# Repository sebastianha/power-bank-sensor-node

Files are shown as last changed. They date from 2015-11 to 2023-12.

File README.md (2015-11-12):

# power-bank-sensor-node
Tutorial how to build a USB-chargeable temperature / humidity / pressure sensor node in a power bank case which transmits the data via 433MHz to a receiver whose serial protocol is MySensor compatible.

## Example

Here is an image of an earlier version of the sensor node:

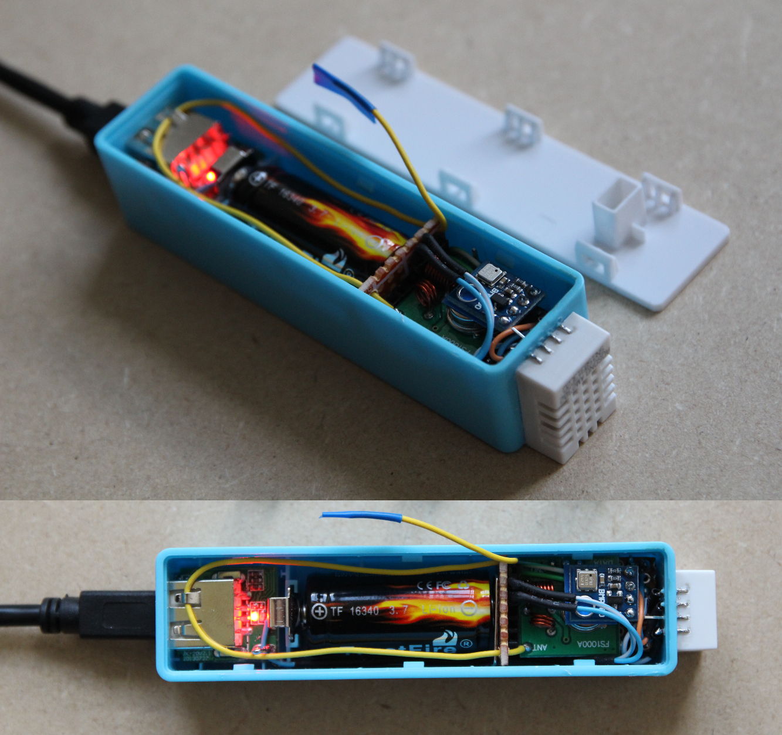
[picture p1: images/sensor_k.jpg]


[Click here for a high-res picture](https://raw.githubusercontent.com/sebastianha/power-bank-sensor-node/master/images/sensor.jpg)

## Prequesites

Here is a list of things to buy:

1. Arduino Pro Mini 8MHz, 3.3V [Ebay](http://www.ebay.de/itm/400985414333)
2. 433 MHz sender module [Ebay](http://www.ebay.de/itm/400985370866)
3. BMP180 pressure sensor [Ebay](http://www.ebay.de/itm/201414876396)
4. DHT22 humidity sensor [Ebay](http://www.ebay.de/itm/400985446261)
5. USB cell phone charger [Ebay](http://www.ebay.de/itm/311142194692)
6. 16340 rechargeable battery [Dealextreme](http://www.dx.com/p/24980)
7. Optional: USB plugs & DS18B20 tempereature sensors [Ebay](http://www.ebay.de/itm/400985334891)

## Schematic

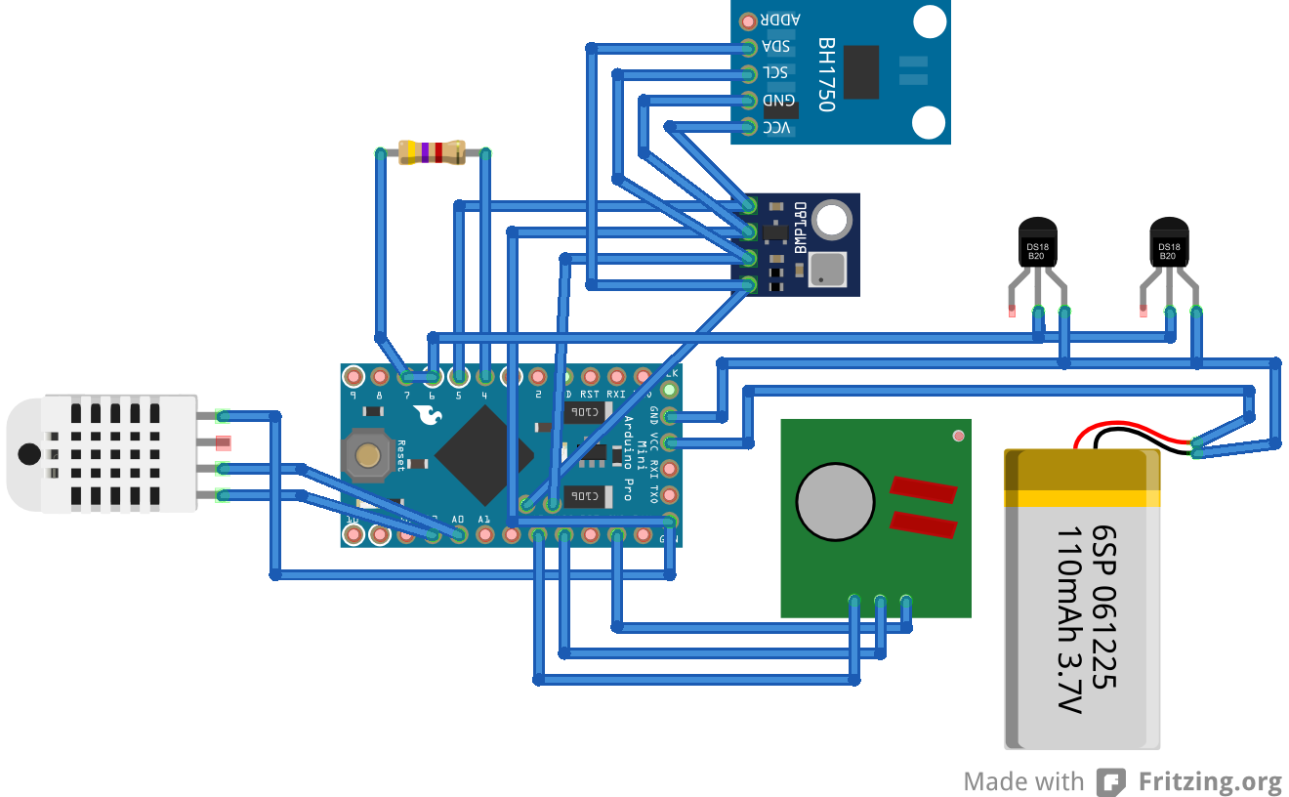
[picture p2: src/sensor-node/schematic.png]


Note: The programming pins of my Arduino seem to have a different order.

## Howto

#### Step 1: Remove unecessary and power hungry parts of the Arduino

Here is the Arduino Pro Mini I used (left picture). First unsolder the reset button (right image, green circle on the left), the power indicator LED (circle in the middle) and the step-down converter on the right.

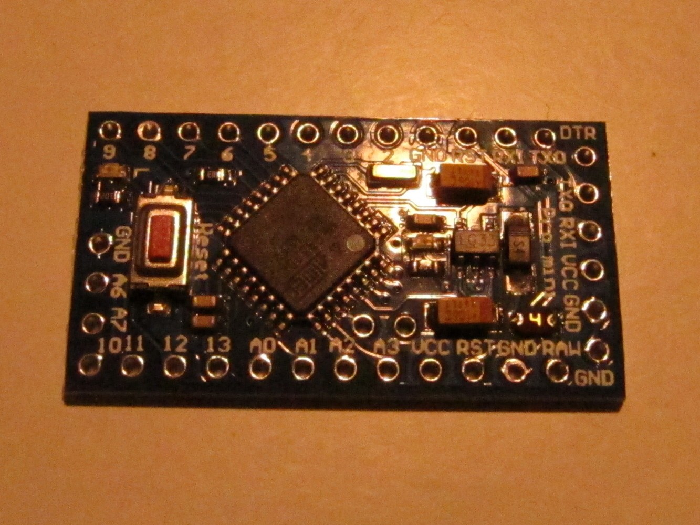
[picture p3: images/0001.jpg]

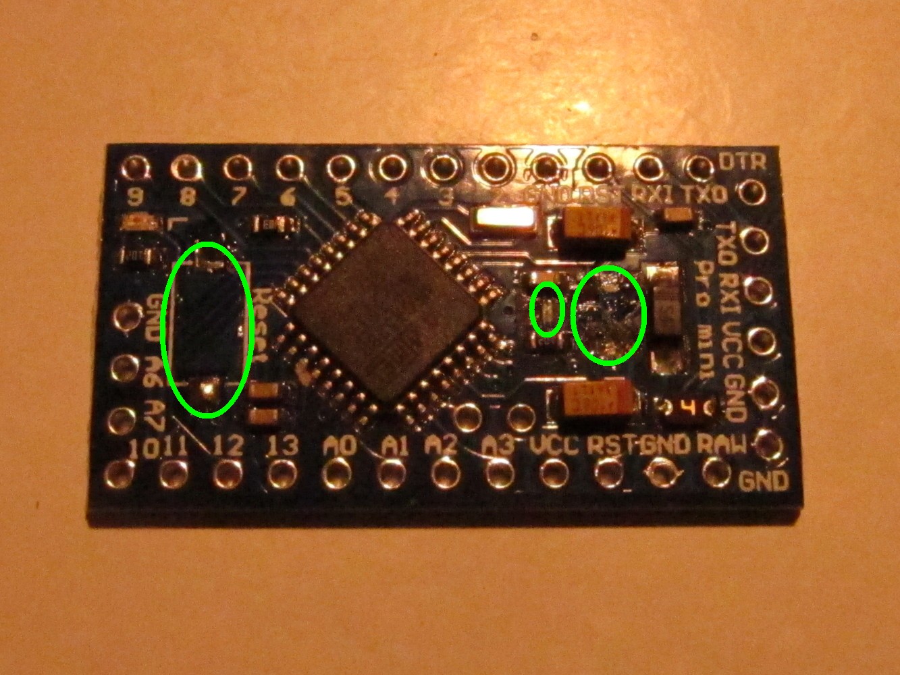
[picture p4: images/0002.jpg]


#### Step 2: Reduce the size of the Arduino

We have to shorten the Arduino so it fits together with the battery into the power bank case. So cut it with a saw between pin 11 and 12 so that pin 12 still remains usable as seen on the left picture. The result can be seen on the right.

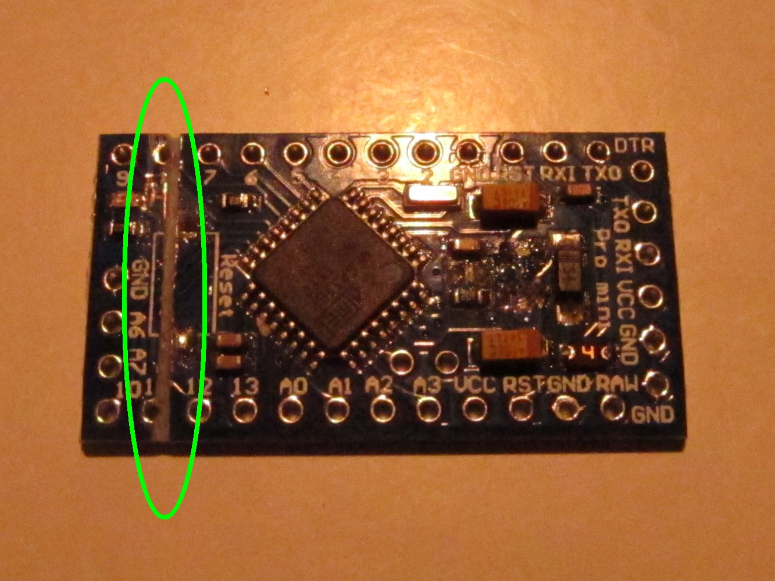
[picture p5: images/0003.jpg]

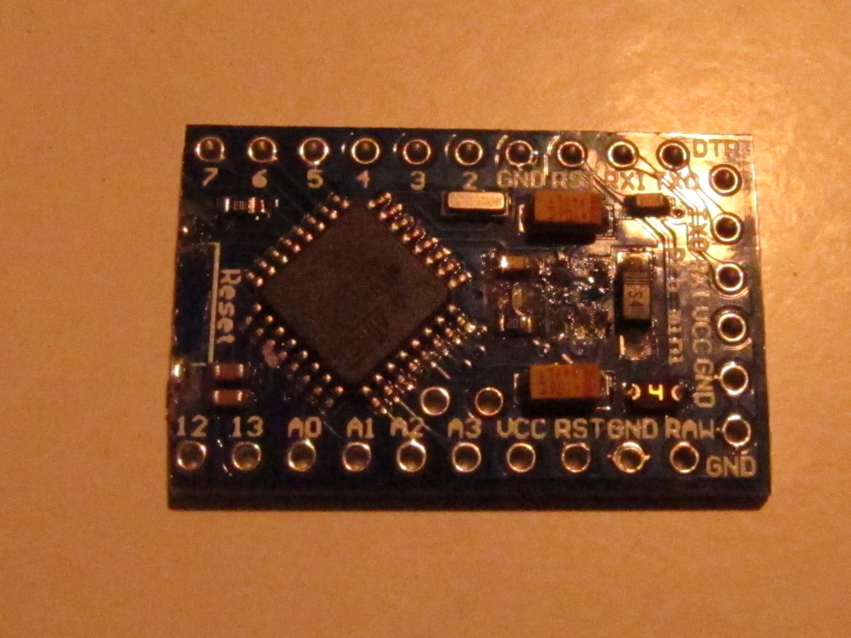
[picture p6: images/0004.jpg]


#### Step 3: Remove the pins of the 433MHz sender

The sender comes with pins that are not needed.

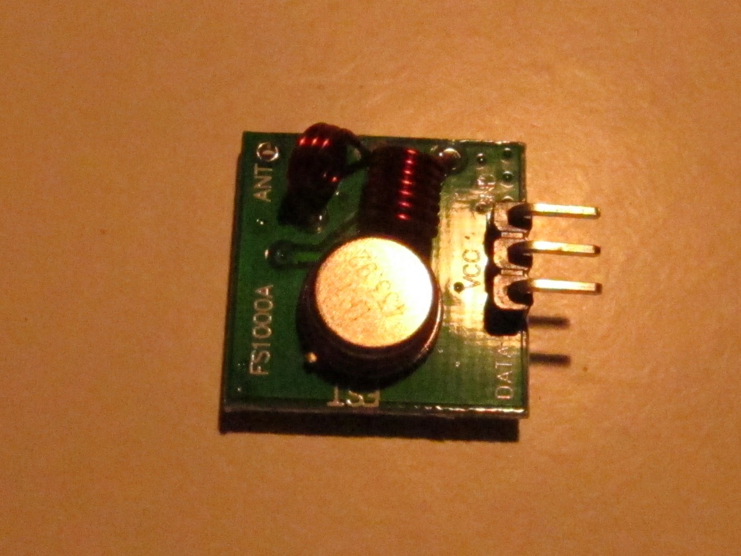
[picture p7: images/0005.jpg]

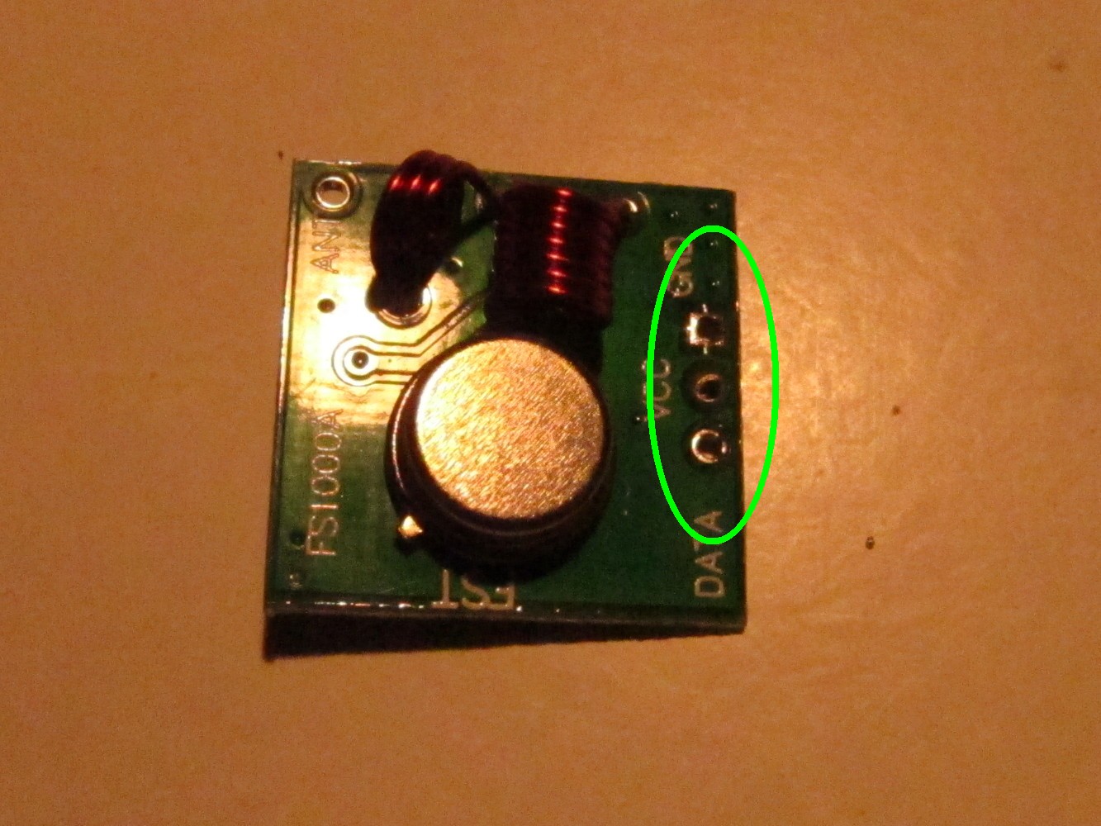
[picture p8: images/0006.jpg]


#### Step 4: Add programming header

Add a female pin header to the Arduino to program it later. The free pin on the right is the second ground pin on the row.

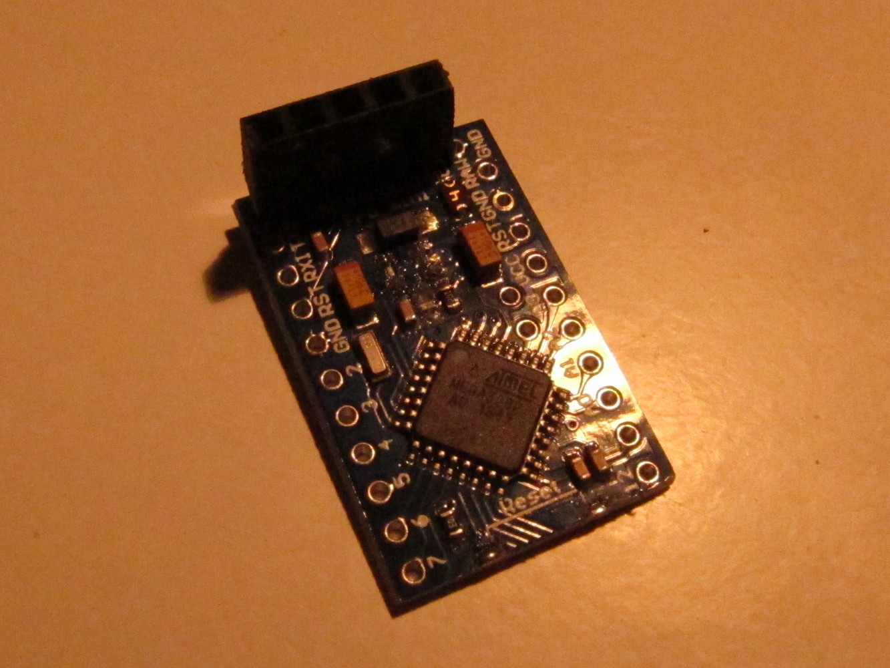
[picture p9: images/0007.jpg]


#### Step 5: Create sender adapter

To connect the sender to the Arduino create an adapter as seen on the left picture. Solder it to GND, VCC and pin A3.

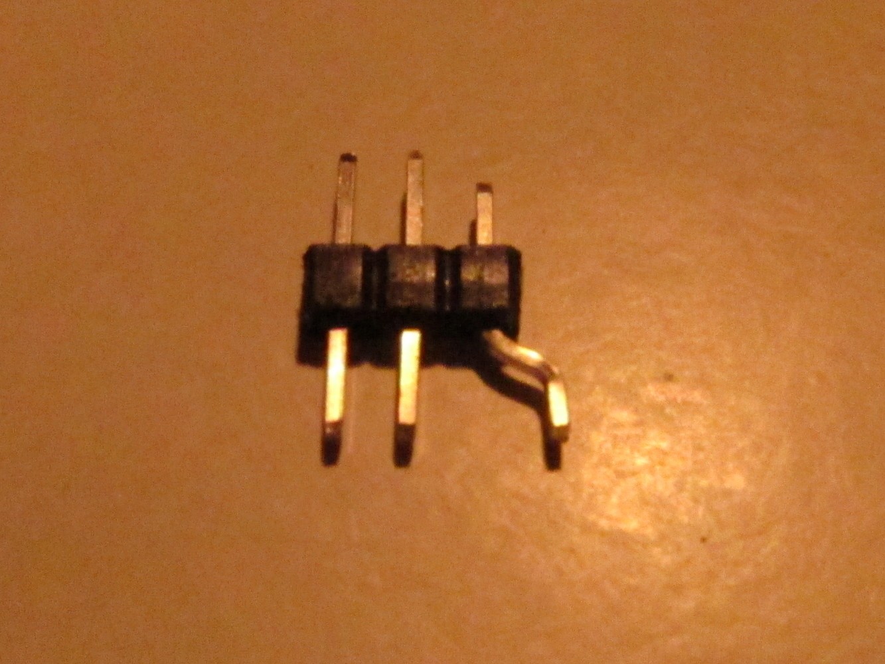
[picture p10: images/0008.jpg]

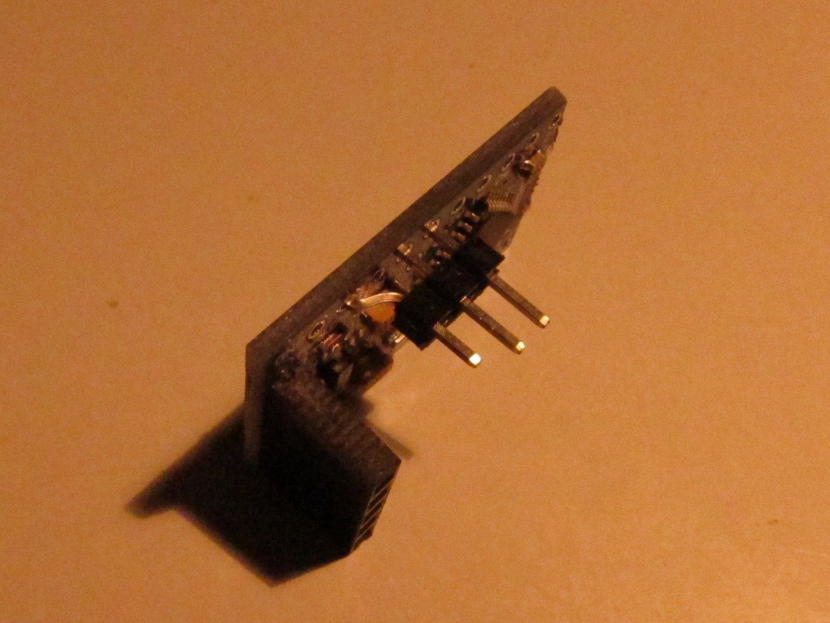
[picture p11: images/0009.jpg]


#### Step 6: Add some cables

Solder two (half blue) cables to the free Arduino GND pin right of the programming headers (green circle at the top). Also add cables to Arduino pin A4 (half green wire) and Arduino A5 (green wire) (green circle in the middle). Remove the plastic connectors of the sender adapter and cut away one section. Then add it on the to straight pins and push it down to the Arduino board as seen on the right picture (green circle)

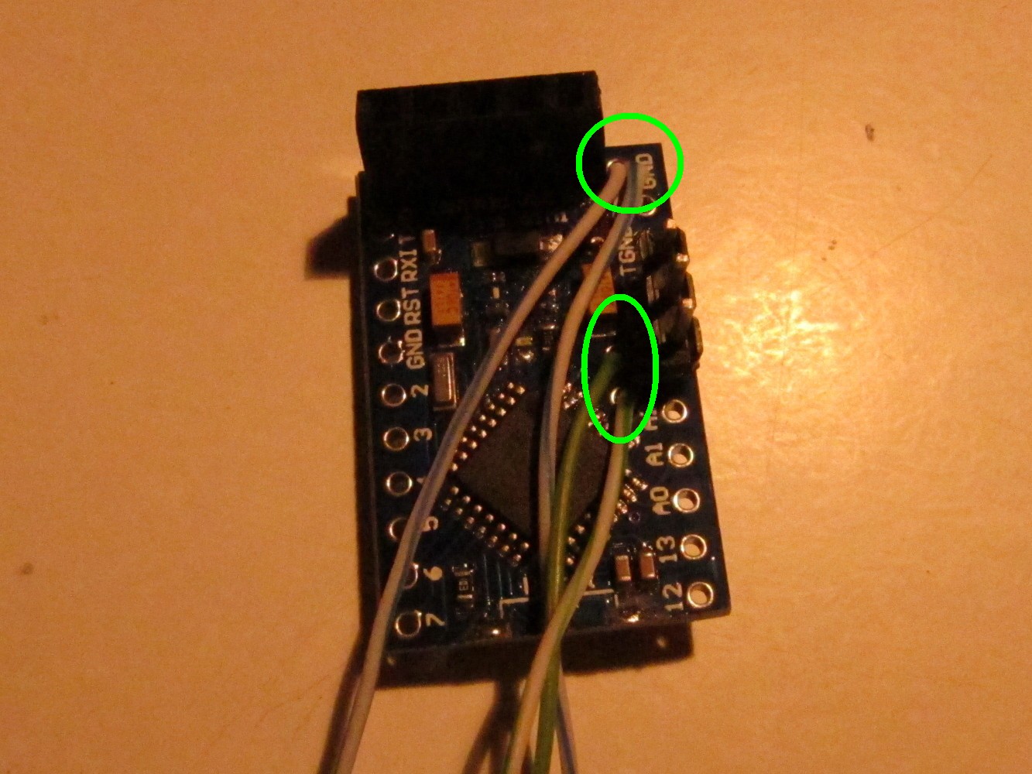
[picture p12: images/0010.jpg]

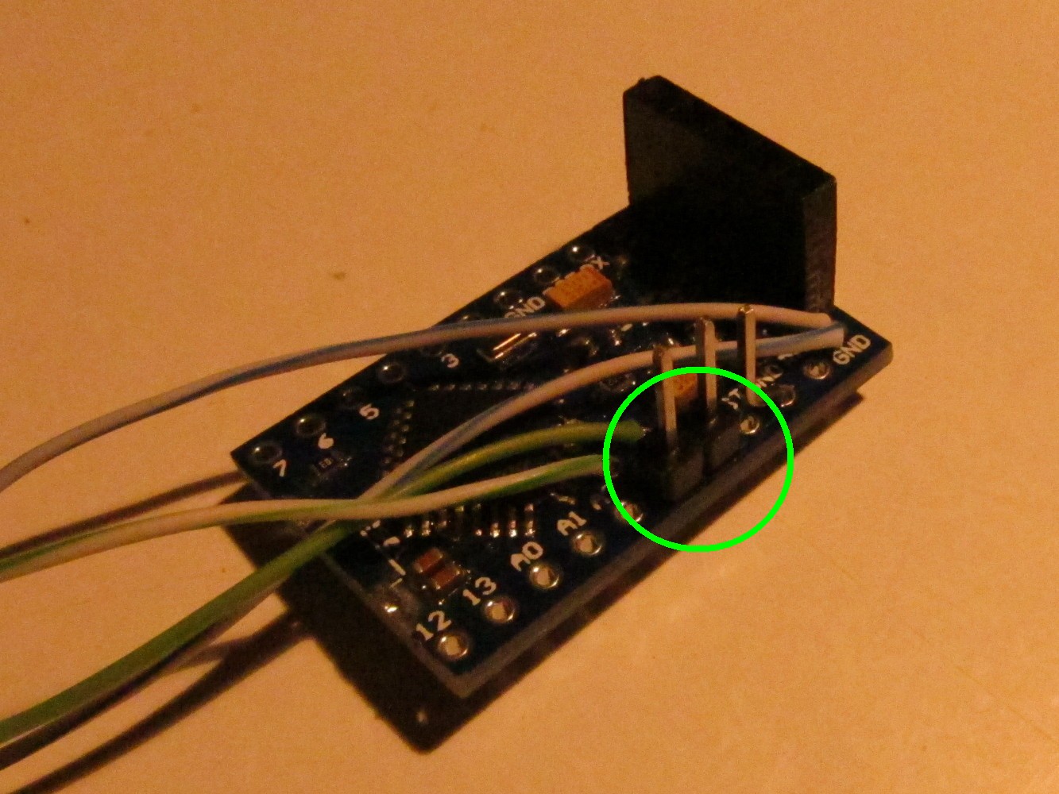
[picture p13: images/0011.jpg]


#### Step 7: Add pull up resistor and connect sender

Solder a 4.7kOhm resistor to Arduino pin 4 and 7 as seen on the left picture (green circle). Then add the sender module on the top connected to the adapter as seen on the picture.

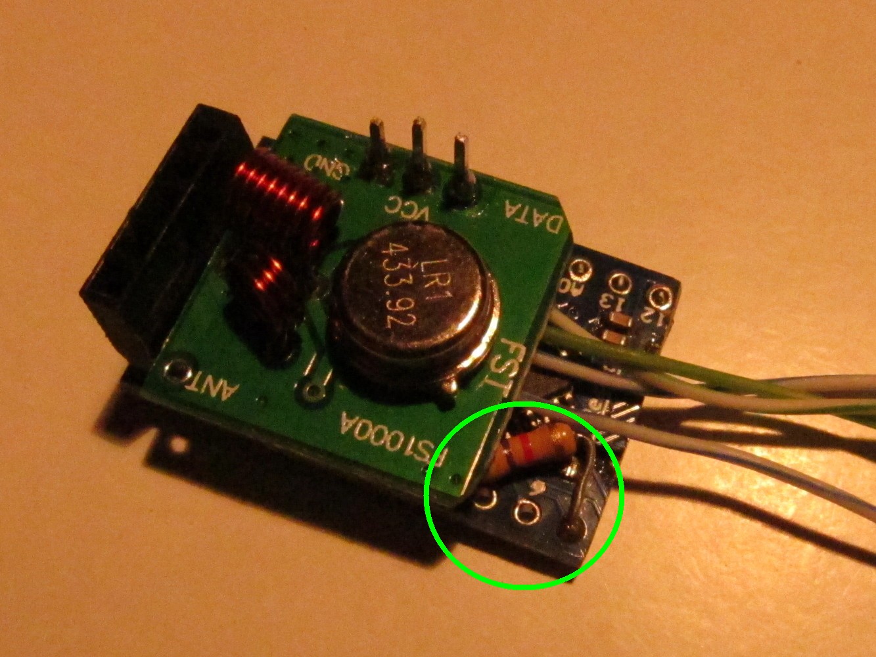
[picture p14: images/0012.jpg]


#### Step 8: Add pin header for the BMP180 sensor

The VCC of the BMP180 sensor will be connected to Arduino pin 5. Therefore a long pin header is soldered to Arduino pin 5 as seen on the picture below (green circle).

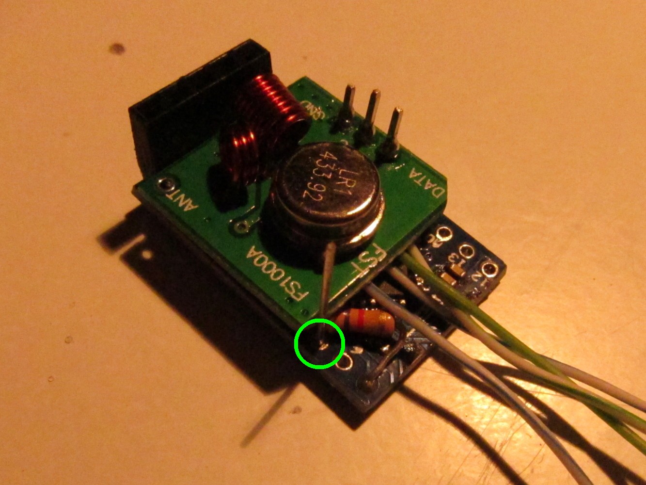
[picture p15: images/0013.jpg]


#### Step 9: Prepare BMP180 sensor

Put a piece of tape on the bottom side of the BMP180 sensor as seen on the right image.

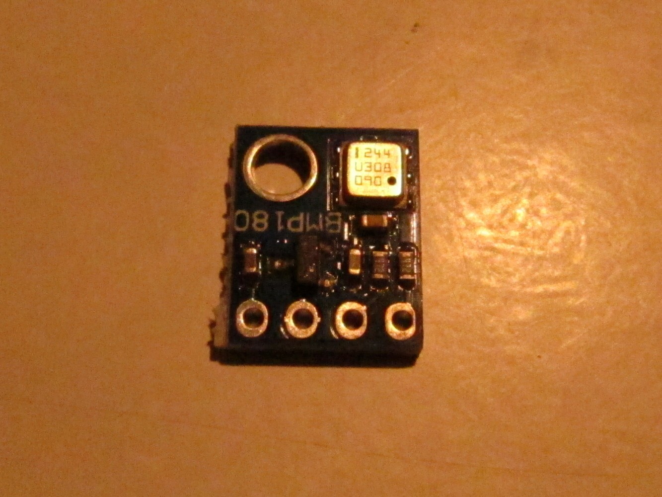
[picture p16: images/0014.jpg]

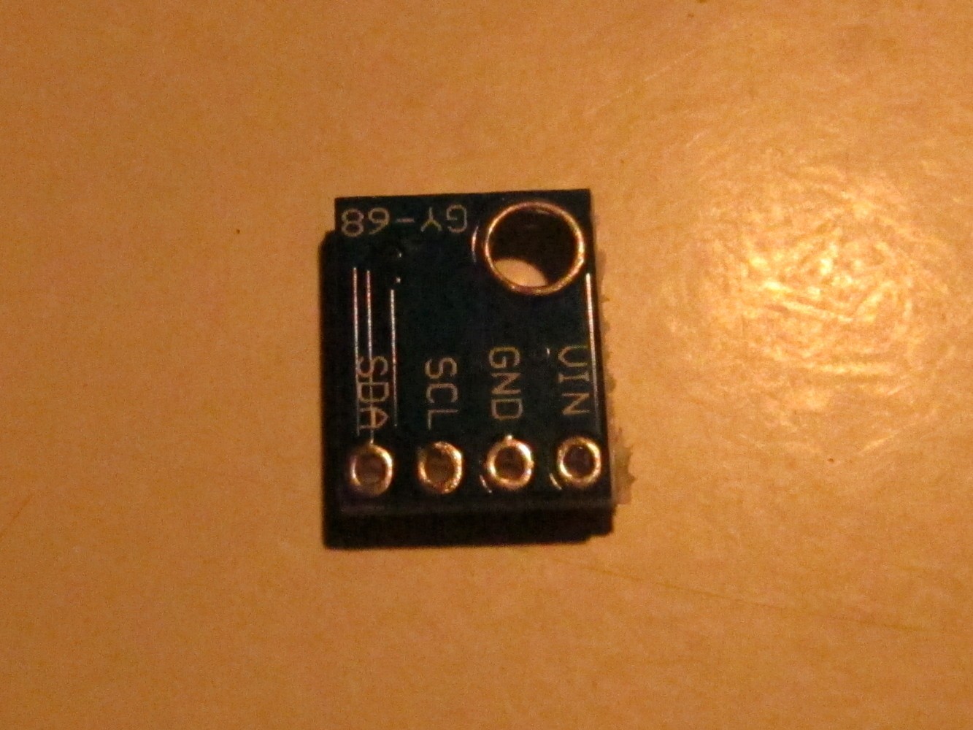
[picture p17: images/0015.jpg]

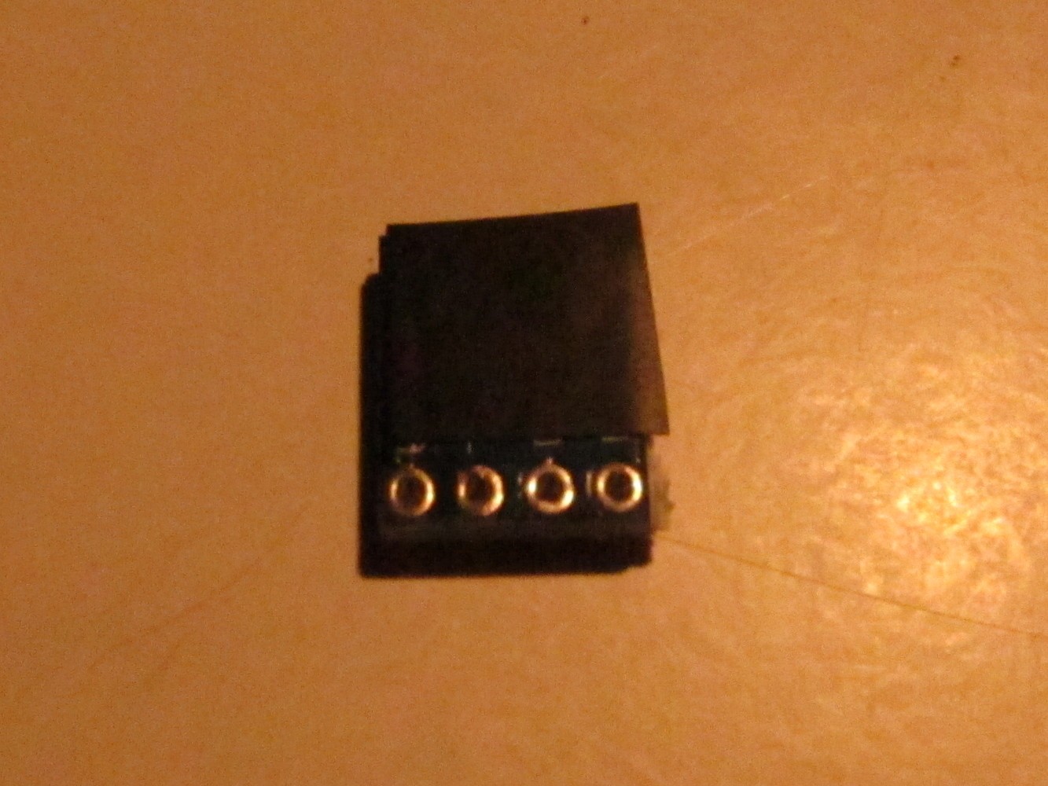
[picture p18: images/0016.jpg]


#### Step 10: Add BMP180 sensor

Cut the green wires and one of the blue ones as seen on the picture. Then solder the BMP180 as seen to the pin header (Arduino pin 5), GND (half blue wire), A5 (green wire) and A4 (half green wire).

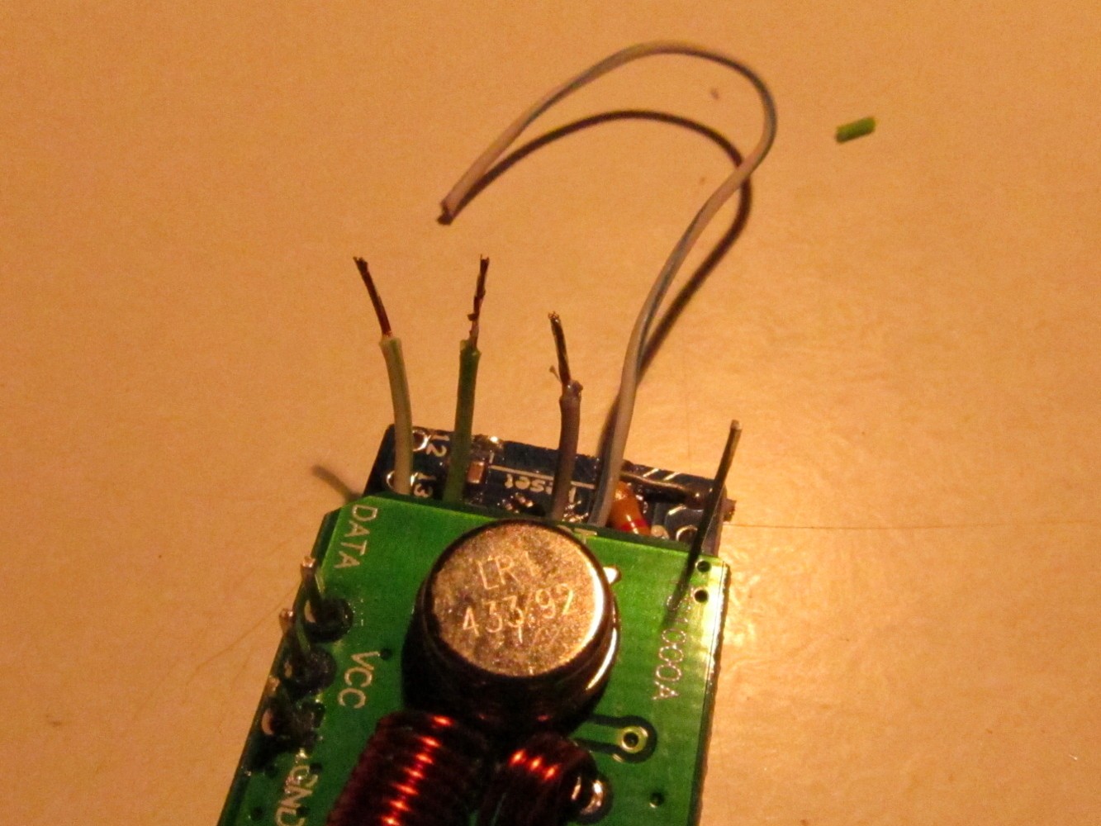
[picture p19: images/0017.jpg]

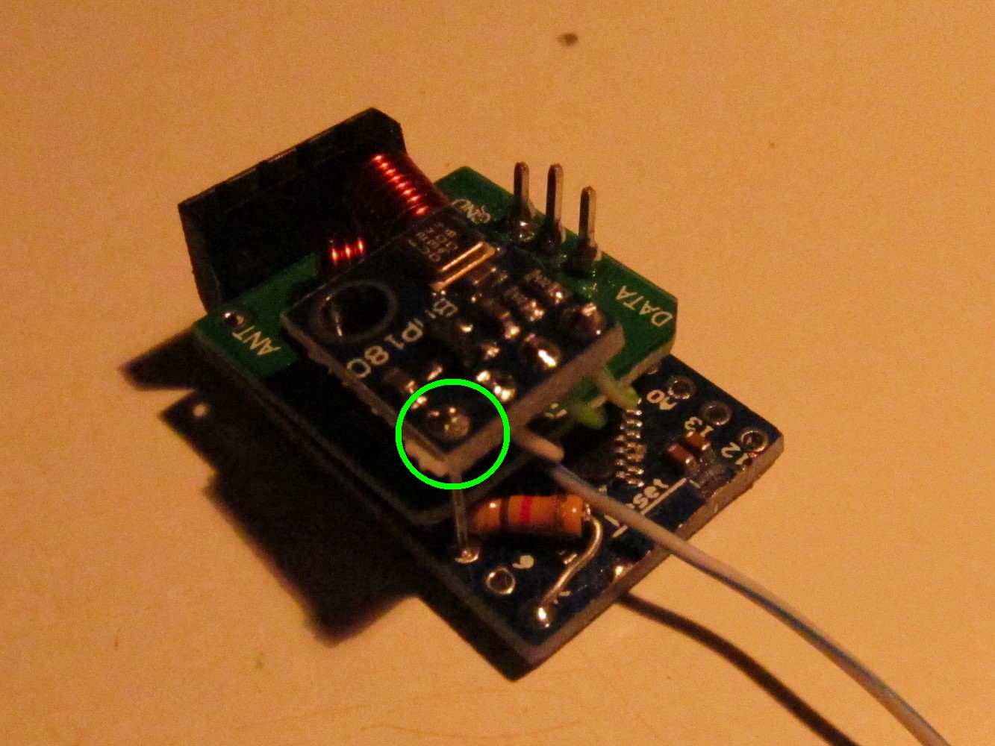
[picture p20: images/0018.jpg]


#### Step 11: Add DS18B20 connector

Solder a long (10cm) wire to Arduino pin 6 as seen on the left picture. On the back side of the Arduino connect pin 6 and pin 7 as seen on the right picture (I forgot it when taking the pictures, that's why it shows a later step).

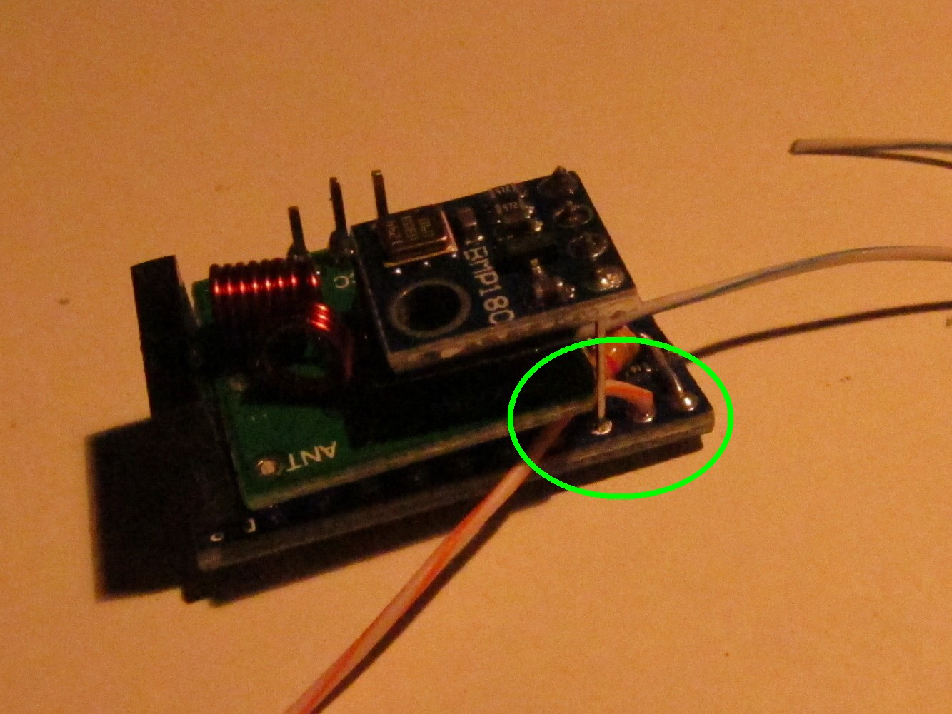
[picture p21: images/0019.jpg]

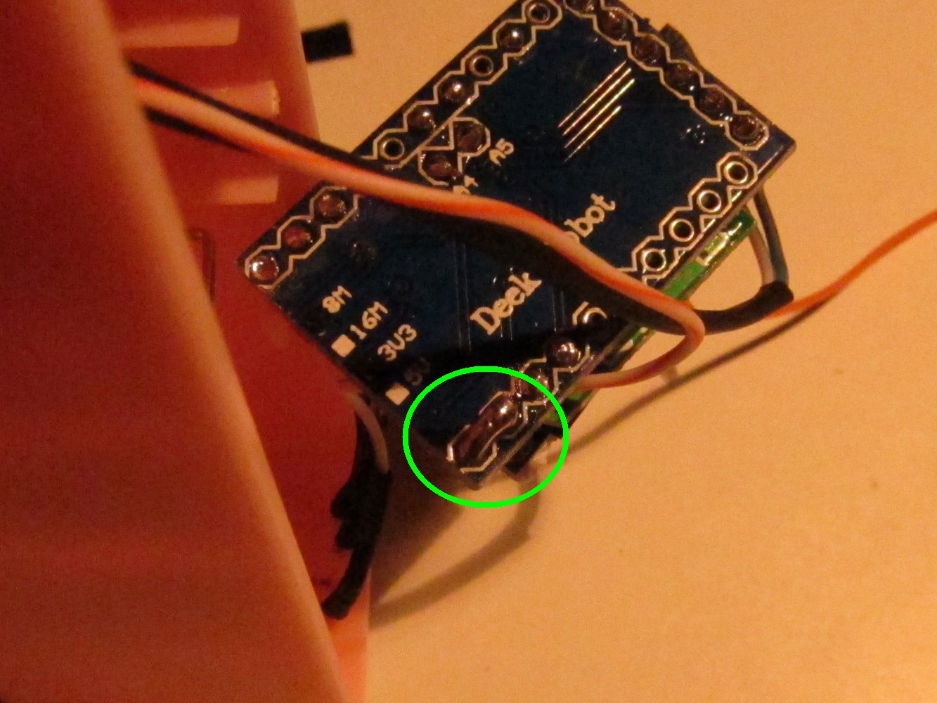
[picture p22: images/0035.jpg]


#### Step 12: The USB power bank cellphone charger case

In general any case like this will work. I found there are small differences between the same looking cases on ebay. Especially when it comes to idle power consumption it might be interesting for this project. As a reference: A "good" case consumes about 0.025-0.050 mAh when idle without anything connected.

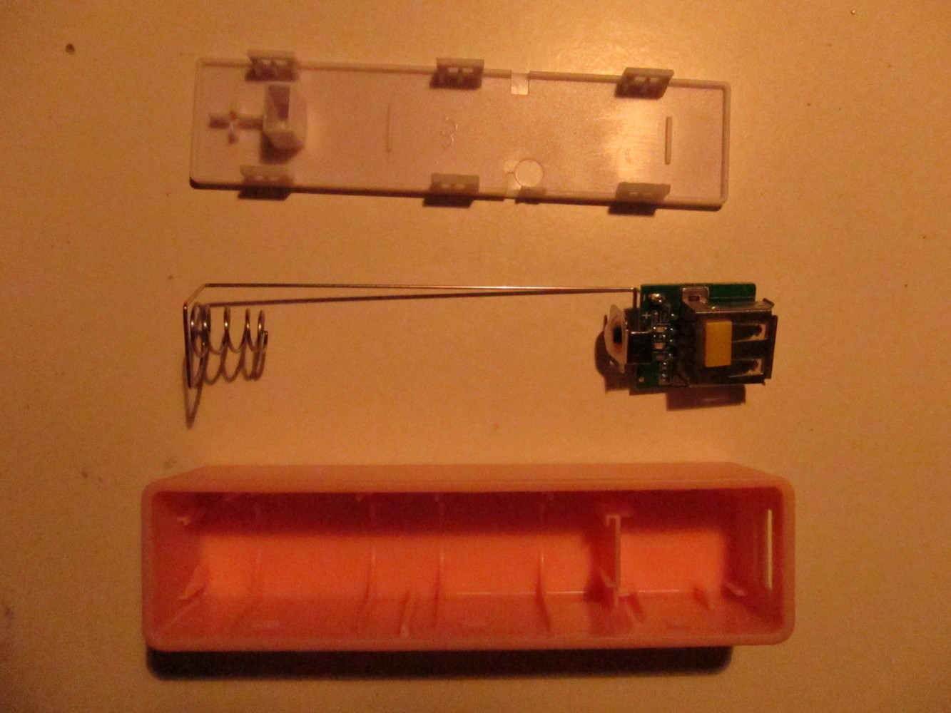
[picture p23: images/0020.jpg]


#### Step 13: Prepare power bank case

The battery holder has to be shortened to fit the 16340 battery. Unsolder it and shorten it as seen on the second picture. Then solder it again to the PCB of the charger (third picture). Check if the battery and the Arduino fits into the case. The result should look like on the most right picture.

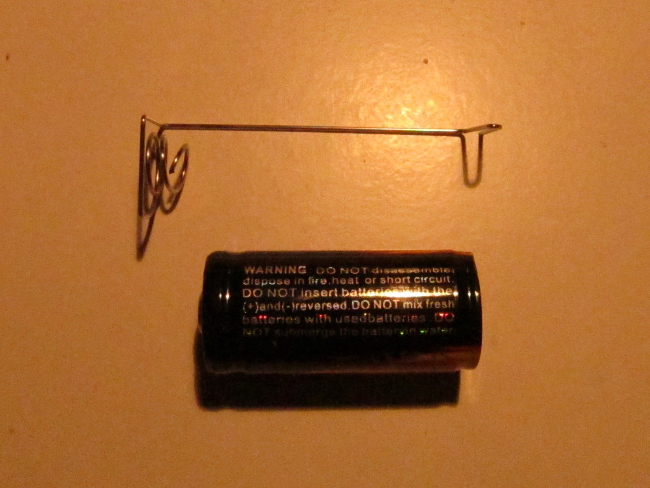
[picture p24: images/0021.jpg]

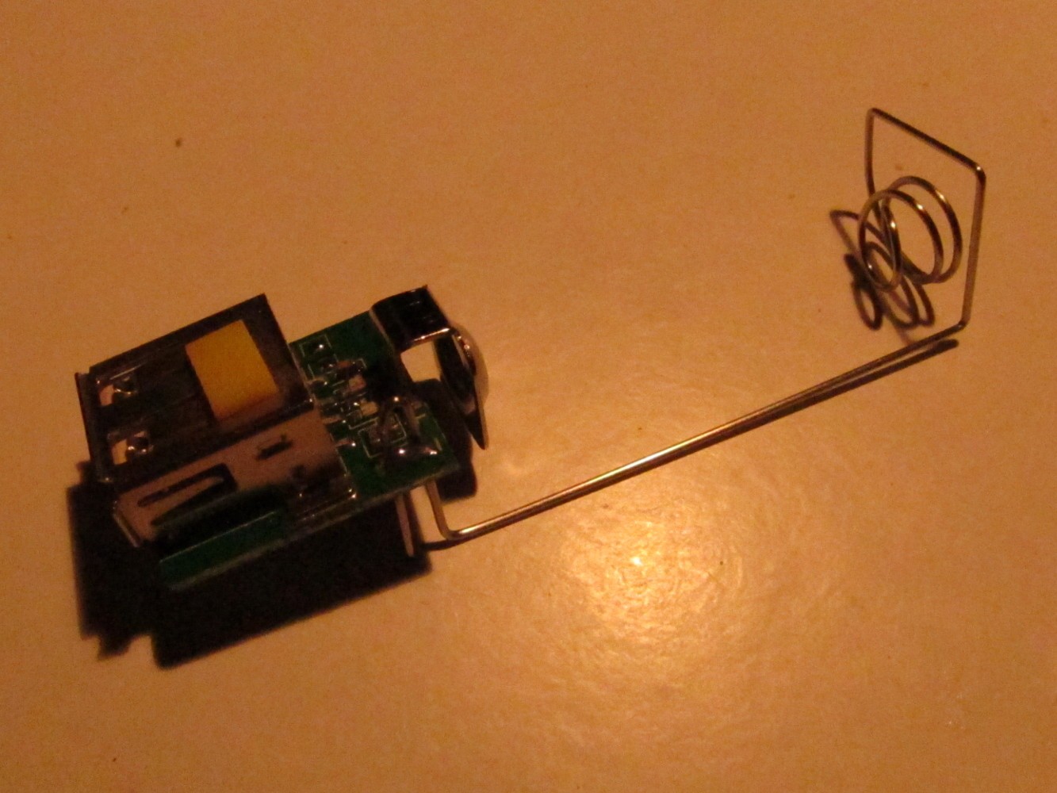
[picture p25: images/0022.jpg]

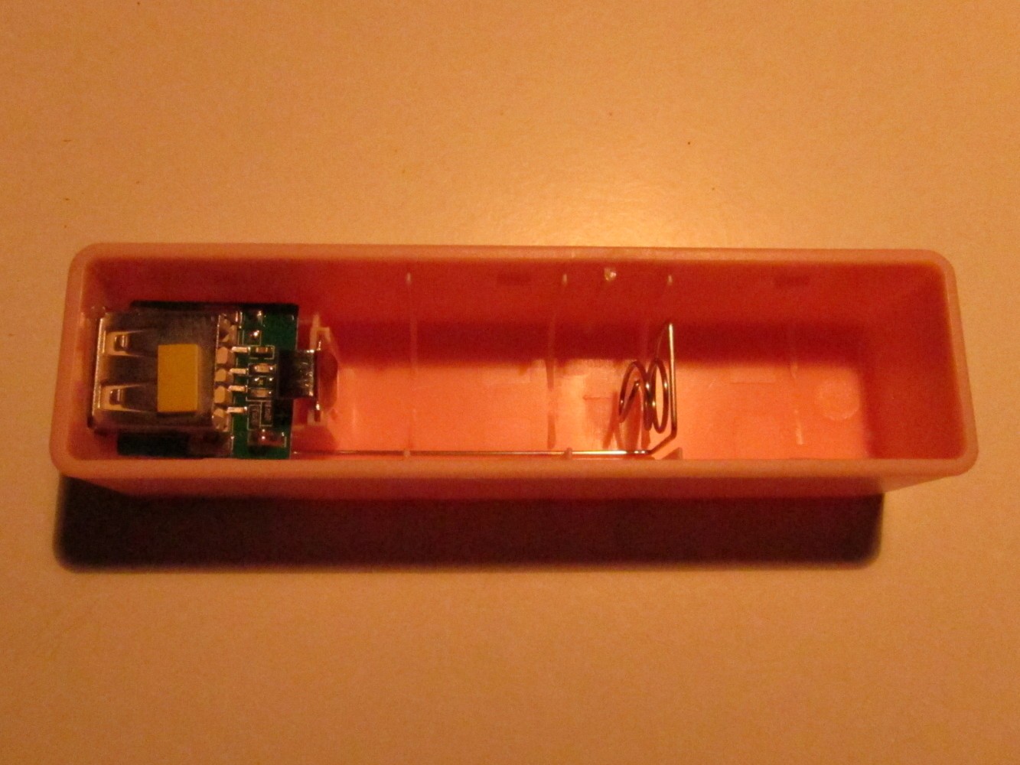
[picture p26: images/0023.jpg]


#### Step 14: Prepare DHT22 sensor

Cut off the upper part of the DTH22 sensor if you like. You could use the loop to fix the case somewhere but the sensor will not fit nicely onto the power bank case. The result is shown on the right picture.

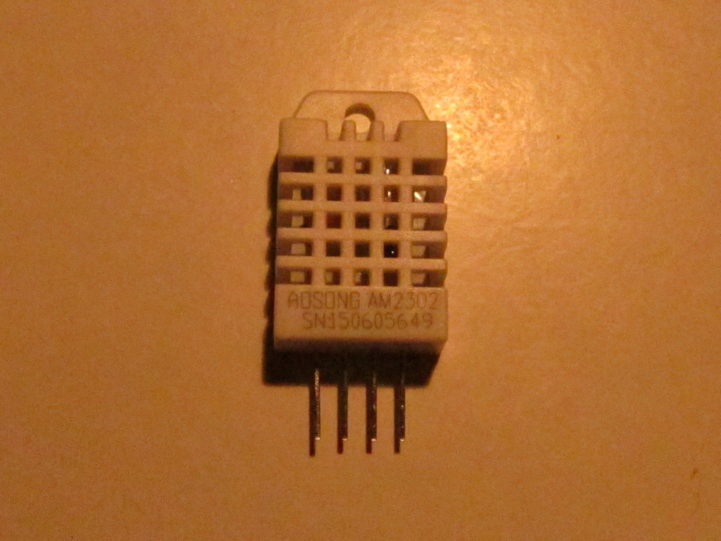
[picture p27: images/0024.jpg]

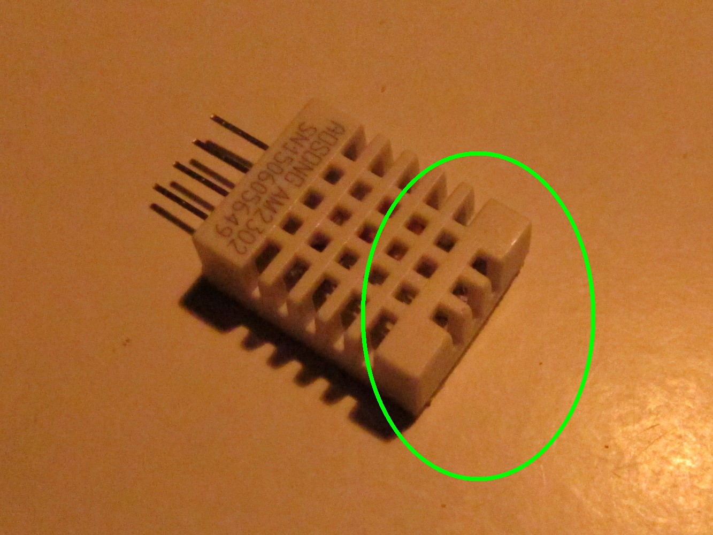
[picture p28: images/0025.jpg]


#### Step 15: Attach DHT22 sensor to power bank case

Pierce the pins of the DHT22 sensor through the case by heating them up with the soldering iron as seen on the left picture. Beware that there has to be enough space for the case cover. Finally, glue it to the case (right picture).

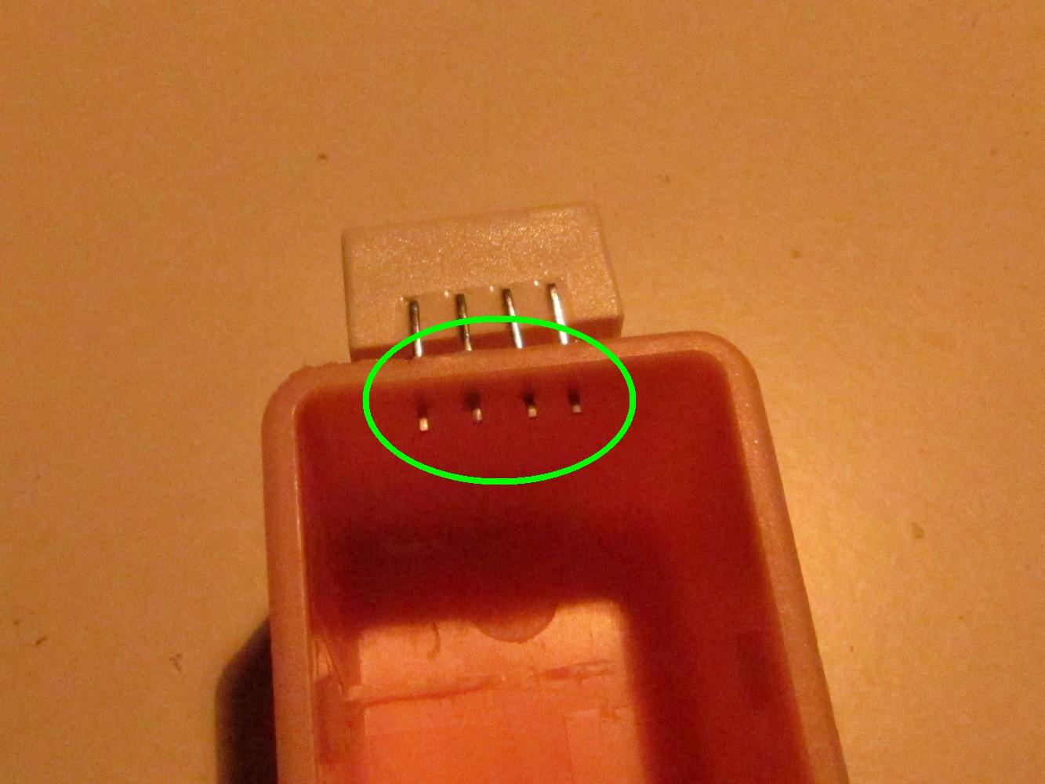
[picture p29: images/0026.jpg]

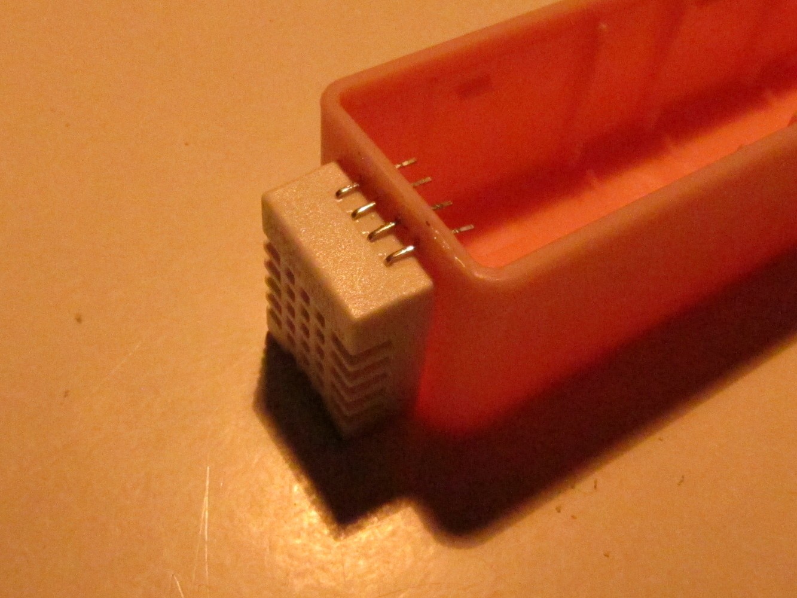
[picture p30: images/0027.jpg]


#### Step 16: Add power cables for the Arduino

Solder a blue cable to the positive pole on the charger PCB and a half blue cable to the negative pole of the charger PCB as seen on the left picture. Cover it with shrinking tube and attach pin headers to it as seen on the right picture.

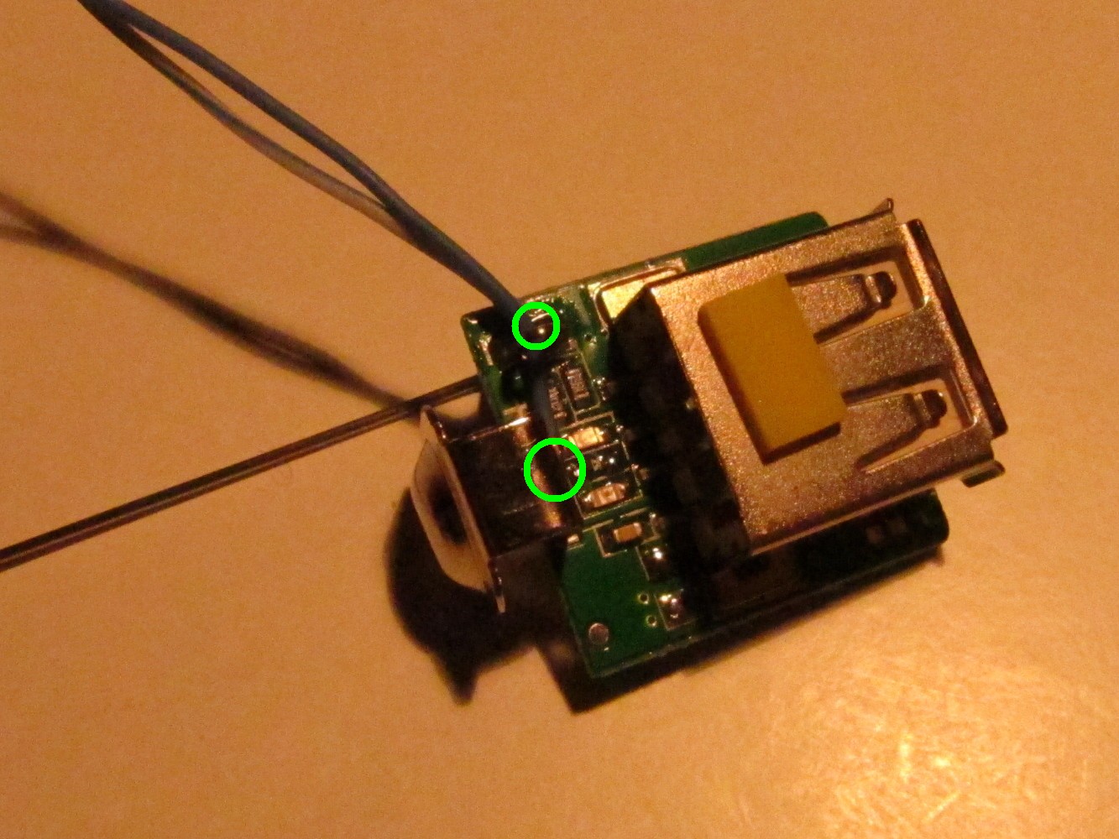
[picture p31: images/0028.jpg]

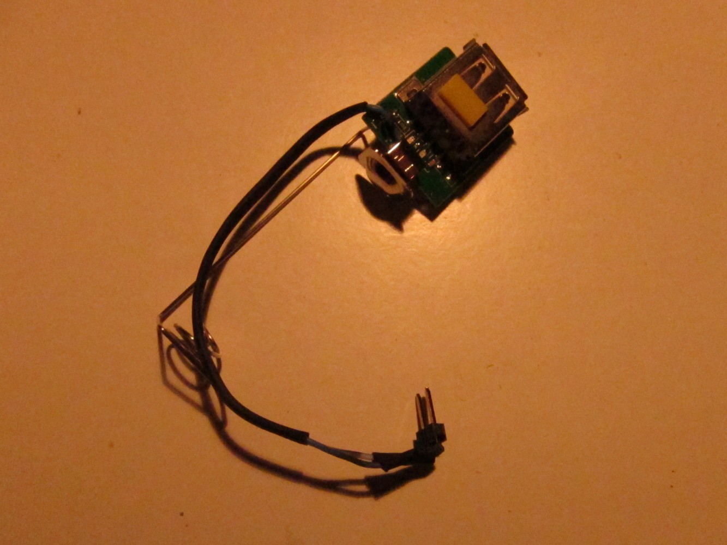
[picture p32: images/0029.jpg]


#### Step 17: Connect DHT22 sensor

Solder a half brown cable to Arduino pin A0 (data) and a brown cable to Arduino pin 13 (VCC) as seen on the left picture. Then connect the DHT22 sensor with these cables and the half blue cable (GND) as seen on the right picture.

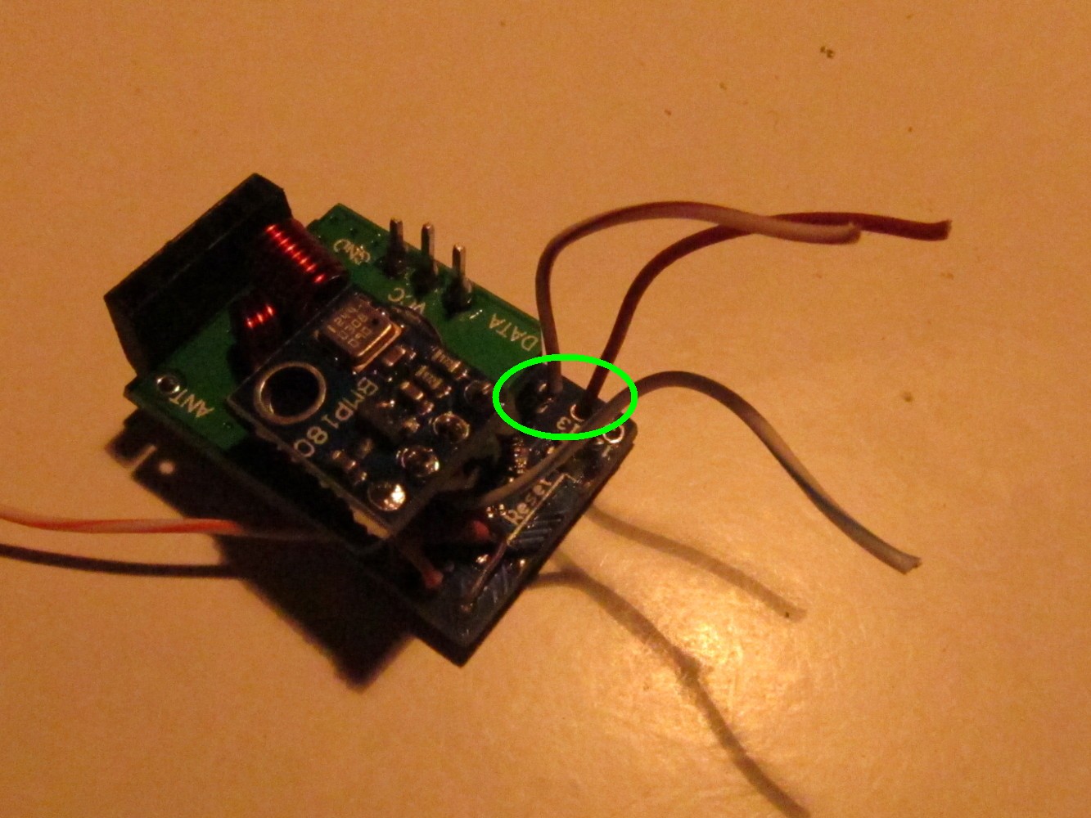
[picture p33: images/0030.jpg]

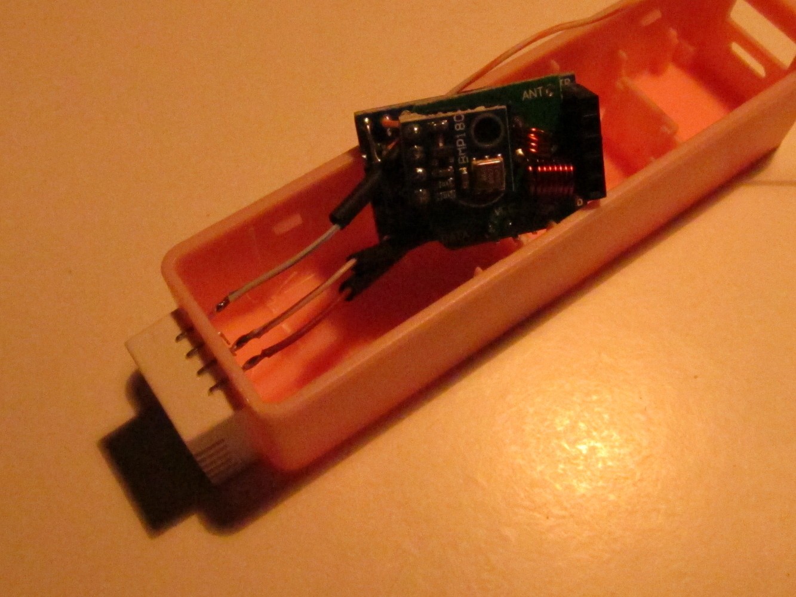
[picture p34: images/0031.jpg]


#### Step 18: Fit everything into the power bank case

Fit everything into the power bank case as seen on the left picture and connect the power connector as seen on the right picture.

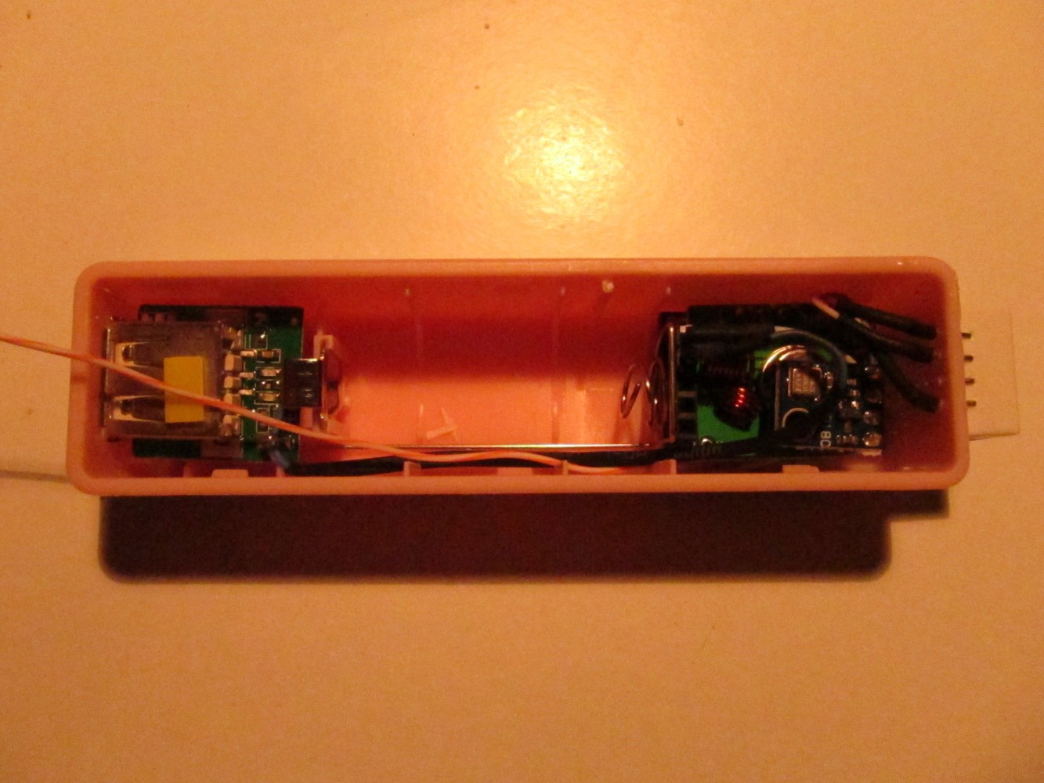
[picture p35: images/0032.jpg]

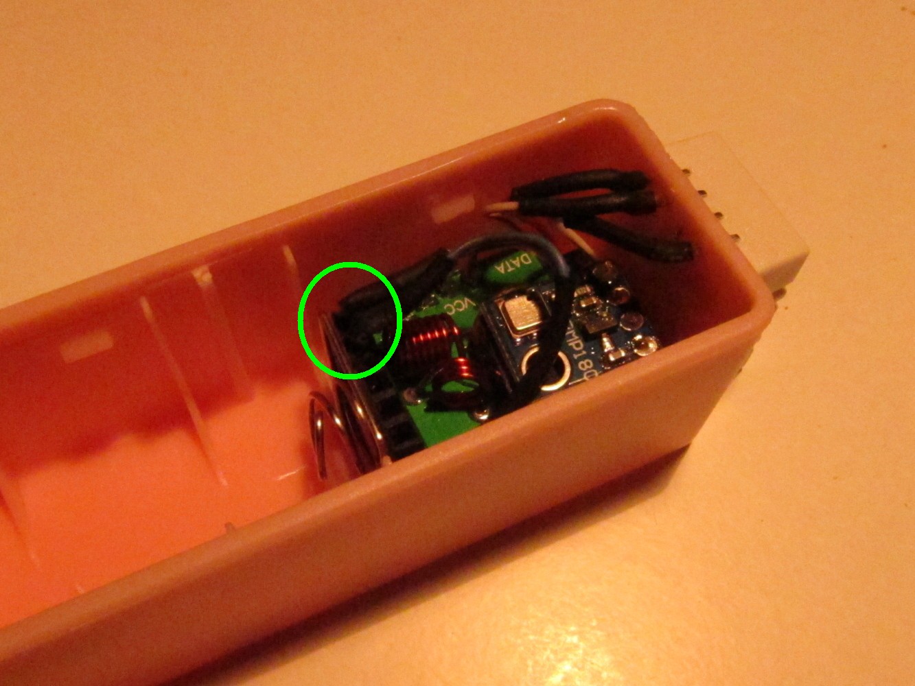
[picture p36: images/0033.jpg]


#### Step 19: Connect DS18B20 data cable

Solder the long, orange cable to the lower USB data connected (the one close to the USB ground).

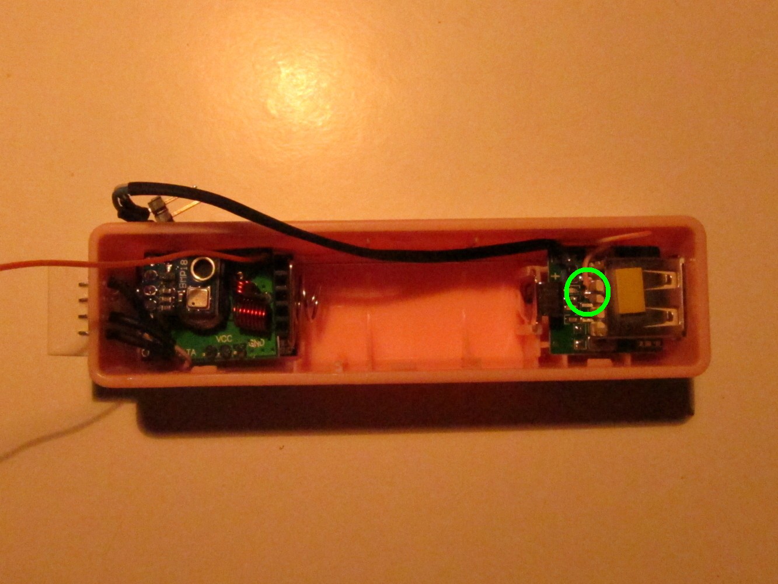
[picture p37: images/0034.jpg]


#### Step 20: Add seperator and attach antenna

Cut a piece of paper as seen on the left picture and place it between the battery holder and the Arduino. Solder a 17.5cm long wire to the antenna pin of the 433MHz sender as seen on the right picture.

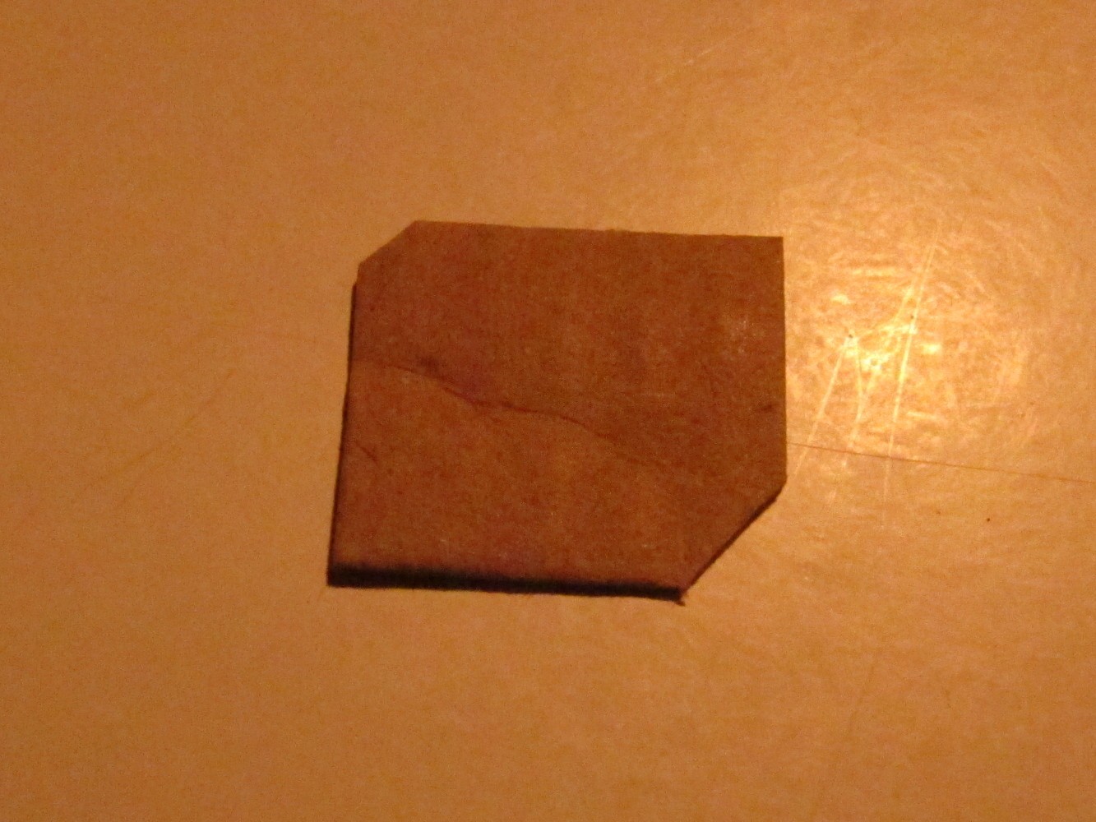
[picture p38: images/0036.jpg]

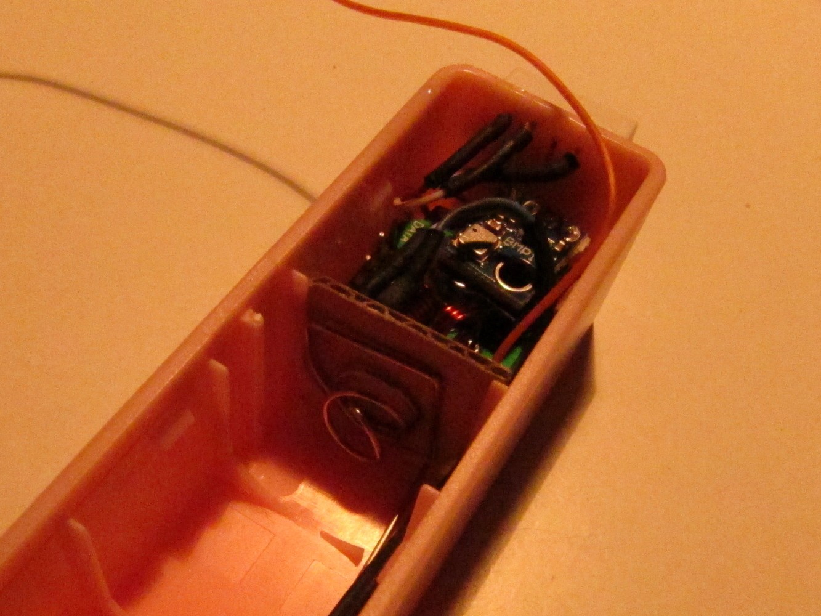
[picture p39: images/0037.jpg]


#### Finish

Assemble everything, it should now look like on the pictures below.

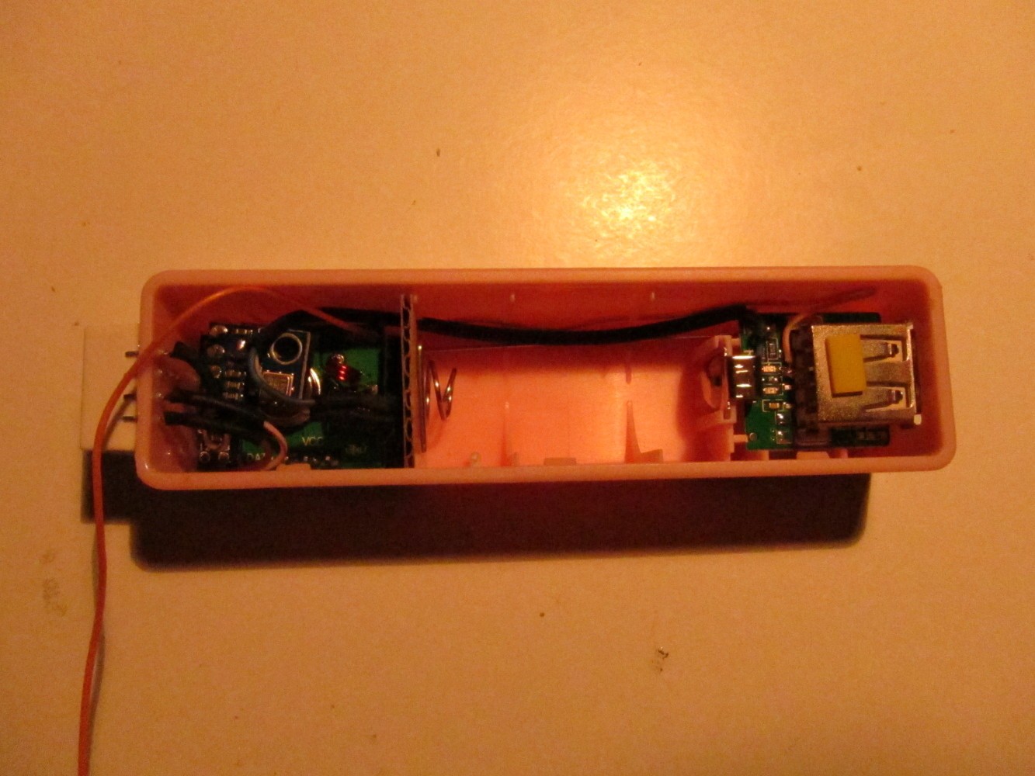
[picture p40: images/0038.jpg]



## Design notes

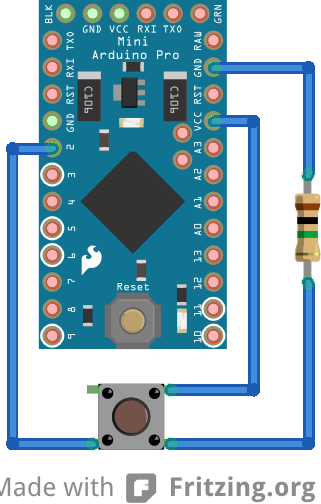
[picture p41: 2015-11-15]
src/window-switch/schematic.png

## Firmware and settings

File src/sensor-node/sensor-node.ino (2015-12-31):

#include <stdint.h>
#include <EEPROM.h>
#include <VirtualWire.h>

/*********************************
***** HARDWARE CONFIGURATION *****
**********************************/

#define RANDOM_PIN              1      // Needs to be an unconnected ANALOG pin to generate UID

#define SLEEP_TIME_8S           7      // Default: 37 for ~5 minutes

#define BATTERY_FULL            4200   // in mV, use max measured voltage
#define BATTERY_EMPTY           2800   // in mV, use cut-off voltage

#define RADIO_RX_PIN            A2     // Not connected
#define RADIO_TX_PIN            A3     // Data pin for sender
#define RADIO_PTT_PIN           2      // Not connected
#define RADIO_REPEAT_MSG        3      // Normally 3 times is enough to ensure data transmission
#define RADIO_BAUD_RATE         2000   // Needs to be adjusted on receiver side, too

#define DHT22_TEMP                     // Enable if DHT22 is connected and temperature should be read
#define DHT22_TEMP_MULTIPLIER   1      // Multiplier
#define DHT22_TEMP_OFFSET       0      // Offset in °C
#define DHT22_HUM                      // Enable if DHT22 is connected and humidity should be read
#define DHT22_HUM_MULTIPLIER    1      // Multiplier
#define DHT22_HUM_OFFSET        0      // Offset in %
#define DHT22_POWER_PIN         13     // Powers the sensor
#define DHT22_PIN               A0     // Data pin for sensor

#define BARO_LIGHT_POWER_PIN    5      // Powers the barometer and or light sensor

#define BARO_TEMP                      // Enable if BMP180 is connected and temperature should be read
#define BARO_TEMP_MULTIPLIER    1      // Multiplier
#define BARO_TEMP_OFFSET        0      // Offset in °C
#define BARO_PRESS                     // Enable if BMP180 is connected and pressure should be read
#define BARO_PRESS_MULTIPLIER   1      // Multiplier
#define BARO_PRESS_OFFSET       0      // Offset in mbar

#define LIGHT                          // Enable if BH1750 is connected and light should be read
#define LIGHT_MULTIPLIER        1      // Multiplier
#define LIGHT_OFFSET            0      // Offset in lux

#define DS18B20                        // Enable if DS18B20 is connected
#define DS18B20_MULTIPLIER      1      // Multiplier
#define DS18B20_OFFSET          0      // Offset in °C
#define DS18B20_POWER_PIN       4      // Powers the sensor
#define DS18B20_PIN             6      // Data pin for sensor

/****************************
***** DO NOT EDIT BELOW *****
*****************************/

// Select sleep method
//#define SLEEP_LOWPOWERLIB // 0.035 mAh
#define SLEEP_NICK // 0.016 mAh

const boolean DEBUG = false;   // Enable debug mode?

#define INT_MIN -32768         // Value for "no sensor value available"
int mp = 0;                    // Message Pointer

const int START_SEQ = 0xFF;    // Start sequence of a message
const uint8_t PROTOCOL_VERSION = 1;

// According to mysensors definition
const int V_TEMP     = 0;
const int V_HUM      = 1;
const int V_PRESSURE = 4;
const int V_LEVEL    = 37;

uint8_t MESSAGE_SEQUENCE_NUMBER = 0;
uint16_t DEVICE_UID = 0;       // is read from EEPROM in setup or generated if not present
                               // Value range is from 10000 to 60000

#ifdef SLEEP_LOWPOWERLIB // https://github.com/rocketscream/Low-Power
  #include <LowPower.h>
#endif

#ifdef SLEEP_NICK // http://www.gammon.com.au/forum/?id=11497
  #include <avr/sleep.h>
  #include <avr/wdt.h>

  ISR (WDT_vect) {
    wdt_disable();
  }

  void sleep1s() {
    // disable ADC
    byte ADCSRA_BACKUP = ADCSRA;
    ADCSRA = 0;

    // clear various "reset" flags
    MCUSR = 0;
    // allow changes, disable reset
    WDTCSR = bit (WDCE) | bit (WDE);
    // set interrupt mode and an interval
    WDTCSR = bit (WDIE) | bit (WDP2) | bit (WDP1);    // set WDIE, and 1 second delay
    wdt_reset();  // pat the dog

    set_sleep_mode (SLEEP_MODE_PWR_DOWN);
    noInterrupts ();           // timed sequence follows
    sleep_enable();

    // turn off brown-out enable in software
    MCUCR = bit (BODS) | bit (BODSE);
    MCUCR = bit (BODS);
    interrupts ();             // guarantees next instruction executed
    sleep_cpu ();

    // cancel sleep as a precaution
    sleep_disable();
    ADCSRA = ADCSRA_BACKUP;
  }
  
  void sleep8s() {
    // disable ADC
    byte ADCSRA_BACKUP = ADCSRA;
    ADCSRA = 0;

    // clear various "reset" flags
    MCUSR = 0;
    // allow changes, disable reset
    WDTCSR = bit (WDCE) | bit (WDE);
    // set interrupt mode and an interval
    WDTCSR = bit (WDIE) | bit (WDP3) | bit (WDP0);    // set WDIE, and 8 seconds delay
    wdt_reset();  // pat the dog

    set_sleep_mode (SLEEP_MODE_PWR_DOWN);
    noInterrupts ();           // timed sequence follows
    sleep_enable();

    // turn off brown-out enable in software
    MCUCR = bit (BODS) | bit (BODSE);
    MCUCR = bit (BODS);
    interrupts ();             // guarantees next instruction executed
    sleep_cpu ();

    // cancel sleep as a precaution
    sleep_disable();
    ADCSRA = ADCSRA_BACKUP;
  }
#endif

#if defined(DHT22_TEMP) || defined(DHT22_HUM)
  #include <dht.h>
  dht DHT;
#endif

#if defined(BARO_TEMP) || defined(BARO_PRESS)
  #include <SFE_BMP180.h>
  SFE_BMP180 pressure;
#endif

#ifdef LIGHT
  #include <Wire.h>
  #include <BH1750.h>
  BH1750 lightMeter;
#endif

#ifdef DS18B20
  #include <OneWire.h>
  OneWire ds(DS18B20_PIN);
#endif

union {
  int i = 0;
  unsigned char b[2];
} uid, bat, temp, hum, baro_t, ds_t1;

union {
  unsigned int u = 0;
  unsigned char b[2];
} light;

union {
  float f = 0;
  unsigned char b[4];
} baro_p;

// from http://provideyourown.com/2012/secret-arduino-voltmeter-measure-battery-voltage/
int readVcc() {
  // Read 1.1V reference against AVcc
  // set the reference to Vcc and the measurement to the internal 1.1V reference
  #if defined(__AVR_ATmega32U4__) || defined(__AVR_ATmega1280__) || defined(__AVR_ATmega2560__)
    ADMUX = _BV(REFS0) | _BV(MUX4) | _BV(MUX3) | _BV(MUX2) | _BV(MUX1);
  #elif defined (__AVR_ATtiny24__) || defined(__AVR_ATtiny44__) || defined(__AVR_ATtiny84__)
    ADMUX = _BV(MUX5) | _BV(MUX0);
  #elif defined (__AVR_ATtiny25__) || defined(__AVR_ATtiny45__) || defined(__AVR_ATtiny85__)
    ADMUX = _BV(MUX3) | _BV(MUX2);
  #else
    ADMUX = _BV(REFS0) | _BV(MUX3) | _BV(MUX2) | _BV(MUX1);
  #endif  
 
  delay(2); // Wait for Vref to settle
  ADCSRA |= _BV(ADSC); // Start conversion
  while (bit_is_set(ADCSRA,ADSC)); // measuring
 
  uint8_t low  = ADCL; // must read ADCL first - it then locks ADCH  
  uint8_t high = ADCH; // unlocks both
 
  long result = (high<<8) | low;
 
  result = 1125300L / result; // Calculate Vcc (in mV); 1125300 = 1.1*1023*1000
  return int(result); // Vcc in millivolts
}

void measure(void) {
  mp = 7; // Set message pointer after battery readings
  // INITIALIZE SENSOR VALUES
  bat.i    = INT_MIN;
  temp.i   = INT_MIN;
  hum.i    = INT_MIN;
  baro_t.i = INT_MIN;
  light.u  = INT_MIN;
  ds_t1.i  = INT_MIN;
  baro_p.f = INT_MIN;


  MESSAGE_SEQUENCE_NUMBER+=1; // increase sequence number to avoid duplicate messages
  if(DEBUG) {
    Serial.print("Message Sequence Number: ");
    Serial.print(MESSAGE_SEQUENCE_NUMBER);
  }

  //               Protocoll
  //               |Message sequence number
  //               ||Device UID
  //               ||| Battery information
  //               ||| | DHT22 Temperature
  //               ||| | |  DHT22 Humidity
  //               ||| | |  |  BMP180 Temperature
  //               ||| | |  |  |  BMP180 Pressure
  //               ||| | |  |  |  |    BH1750 Light
  //               ||| | |  |  |  |    |  DS18B20 Temperatures
  //               ||| | |  |  |  |    |  |
  byte msg[28] = "S    BBTTTHHHTTTPPPPPLLLTTT";
  //              012345678901234567890123456

  // copy static values to message
  memcpy(msg+0,  &START_SEQ, 1);
  memcpy(msg+1,  &PROTOCOL_VERSION, 1);
  memcpy(msg+2,  &MESSAGE_SEQUENCE_NUMBER, 1);
  memcpy(msg+3,  &DEVICE_UID, 2);
  
  /*************************
  *** READ BATTERY START ***
  **************************/
  int batMv = readVcc();
  bat.i = (float(batMv-BATTERY_EMPTY) / float(BATTERY_FULL-BATTERY_EMPTY)) * 10000.0f;
  if(bat.i > 10000)
    bat.i = 10000;
  if(DEBUG) {
    Serial.print("   Battery: ");
    Serial.print(batMv);
    Serial.print(" mV (");
    Serial.print(float(bat.i/100.0f));
    Serial.println(" %)");
  }
  memcpy(msg+5, bat.b, 2);
  /*************************
  ***  READ BATTERY END  ***
  **************************/
  
  // Power up sensors and wait some time to "charge"
  #if defined(DHT22_TEMP) || defined(DHT22_HUM)
    digitalWrite(DHT22_POWER_PIN, HIGH);
    digitalWrite(DHT22_PIN, HIGH);
  #endif
  #ifdef DS18B20
    digitalWrite(DS18B20_POWER_PIN, HIGH);
  #endif
  
  delay(700);
  
  /*************************
  ***  READ DHT22 START  ***
  **************************/
  #if defined(DHT22_TEMP) || defined(DHT22_HUM)
    if(DHT.read22(DHT22_PIN) == DHTLIB_OK) {
      temp.i = int((DHT.temperature * DHT22_TEMP_MULTIPLIER + DHT22_TEMP_OFFSET) * 100);
      hum.i  = int((DHT.humidity    * DHT22_HUM_MULTIPLIER  + DHT22_HUM_OFFSET ) * 100);

      if(DEBUG) {
        Serial.print("Temp1: ");
        Serial.print(float(temp.i/100.0f));
        Serial.print(" C   Humid: ");
        Serial.print(float(hum.i/100.0f));
        Serial.print(" %");
      }
    }

    #ifdef DHT22_TEMP
      memcpy(msg+mp+0, &V_TEMP, 1);
      memcpy(msg+mp+1, temp.b, 2);
      mp += 3;
    #endif
    #ifdef DHT22_HUM
      memcpy(msg+mp+0, &V_HUM, 1);
      memcpy(msg+mp+1, hum.b, 2);
      mp += 3;
    #endif
  #endif
  /*************************
  ***   READ DHT22 END   ***
  **************************/

  /*************************
  ***   READ BMP START   ***
  **************************/
  #if defined(BARO_TEMP) || defined(BARO_PRESS)
    char status;
    double T,P;

    status = pressure.startTemperature();
    if (status != 0) {
      delay(status);
      status = pressure.getTemperature(T);
      if (status != 0) {
        status = pressure.startPressure(3);
        if (status != 0) {
          delay(status);
          status = pressure.getPressure(P,T);
          if (status != 0) {
            baro_t.i = int(( T * BARO_TEMP_MULTIPLIER  + BARO_TEMP_OFFSET ) * 100);
            baro_p.f = float(P * BARO_PRESS_MULTIPLIER + BARO_PRESS_OFFSET);
            if(DEBUG) {
              Serial.print("   Temp2: ");
              Serial.print(float(baro_t.i/100.0f));
              Serial.print(" C   Press: ");
              Serial.print(float(baro_p.f));
              Serial.print(" mbar");
            }
          }
        }
      }
    }

    #ifdef BARO_TEMP
      memcpy(msg+mp+0, &V_TEMP, 1);
      memcpy(msg+mp+1, baro_t.b, 2);
      mp += 3;
    #endif
    #ifdef BARO_PRESS
      memcpy(msg+mp+0, &V_PRESSURE, 1);
      memcpy(msg+mp+1, baro_p.b, 4);
      mp += 5;
    #endif
  #endif
  /*************************
  ***    READ BMP END    ***
  **************************/

  /*************************
  ***  READ LIGHT START  ***
  **************************/
  #ifdef LIGHT
    lightMeter.begin(BH1750_ONE_TIME_HIGH_RES_MODE);
    unsigned int lux = lightMeter.readLightLevel();
	light.u = lux * LIGHT_MULTIPLIER + LIGHT_OFFSET;
    if(DEBUG) {
      Serial.print("   Light: ");
      Serial.print(light.u);
      Serial.print(" lx");
    }

    memcpy(msg+mp+0, &V_LEVEL, 1);
    memcpy(msg+mp+1, light.b, 2);
    mp += 3;
  #endif
  /*************************
  ***   READ LIGHT END   ***
  **************************/
  
  /*************************
  *** READ DS18B20 START ***
  **************************/
  #ifdef DS18B20
    byte addr[8];
    byte data[12];
    while(ds.search(addr)) {
      if(!OneWire::crc8(addr, 7) != addr[7]) {
        ds_t1.i  = INT_MIN;
        ds.reset();
        ds.select(addr);
        ds.write(0x44, 1);
        #ifdef SLEEP_LOWPOWERLIB
          LowPower.powerDown(SLEEP_1S, ADC_OFF, BOD_OFF);
        #endif
        #ifdef SLEEP_NICK
          sleep1s();
        #endif
        #if !defined(SLEEP_LOWPOWERLIB) && !defined(SLEEP_NICK)
          delay(1000);
        #endif
        ds.reset();
        ds.select(addr);
        ds.write(0xBE);
        for (int i = 0; i < 9; i++) {
          data[i] = ds.read();
        }
        int16_t raw = (data[1] << 8) | data[0];
        byte cfg = (data[4] & 0x60);
        if (cfg == 0x00) raw = raw & ~7;  // 9 bit resolution, 93.75 ms
        else if (cfg == 0x20) raw = raw & ~3; // 10 bit res, 187.5 ms
        else if (cfg == 0x40) raw = raw & ~1; // 11 bit res, 375 ms
        ds_t1.i = int(((raw / 16.0) * DS18B20_MULTIPLIER + DS18B20_OFFSET) * 100);
        if(DEBUG) {
          Serial.print("   Temp3: ");
          Serial.print(float(ds_t1.i/100.0f));
          Serial.print(" C");
        }

        memcpy(msg+mp+0, &V_TEMP, 1);
        memcpy(msg+mp+1, ds_t1.b, 2);
        mp += 3;
      }
    }
    ds.reset_search();
  #endif
  /*************************
  ***  READ DS18B20 END  ***
  **************************/

  if(DEBUG) Serial.println();

  // Power down sensors
  #if defined(DHT22_TEMP) || defined(DHT22_HUM)
    digitalWrite(DHT22_POWER_PIN, LOW);
    digitalWrite(DHT22_PIN, LOW);
  #endif
  #ifdef DS18B20
    digitalWrite(DS18B20_POWER_PIN, LOW);
  #endif

  // Send data
  for(int i=0; i<RADIO_REPEAT_MSG; i++) {
    vw_send((uint8_t *)msg, mp);
    vw_wait_tx();
    delay(100);
  }
}

void setup(void) {
  if(DEBUG) Serial.begin(57600);
  
  if(DEBUG) {
    Serial.print("PROTOCOL_VERSION: ");
    Serial.println(PROTOCOL_VERSION);
  }
  
  randomSeed(analogRead(RANDOM_PIN));

  // Clear EEPROM DEVICE_UID
  //EEPROM.write(0, 0);
  //EEPROM.write(1, 0);

  uid.b[0] = EEPROM.read(0);
  uid.b[1] = EEPROM.read(1);
  DEVICE_UID = uint16_t(uid.i);
  if(DEVICE_UID == 0) {
    if(DEBUG) Serial.println("Generating new DEVICE_UID because nothing found in EEPROM");
    DEVICE_UID = random(10000, 60000); 
    uid.i = DEVICE_UID;
    EEPROM.write(0, uid.b[0]);
    EEPROM.write(1, uid.b[1]);
  }
  if(DEBUG) {
    Serial.print("DEVICE_UID:       ");
    Serial.println(DEVICE_UID);
  }

  vw_set_tx_pin(RADIO_TX_PIN);
  vw_set_rx_pin(RADIO_RX_PIN);   // Not connected
  vw_set_ptt_pin(RADIO_PTT_PIN); // Not connected
  vw_setup(RADIO_BAUD_RATE);

  #if defined(DHT22_TEMP) || defined(DHT22_HUM)
    pinMode(DHT22_POWER_PIN, OUTPUT);
    pinMode(DHT22_PIN, OUTPUT);
  #endif

  #if defined(BARO_TEMP) || defined(BARO_PRESS) || defined(LIGHT)
    pinMode(BARO_LIGHT_POWER_PIN, OUTPUT);
    digitalWrite(BARO_LIGHT_POWER_PIN, HIGH);
  #endif

  #if defined(BARO_TEMP) || defined(BARO_PRESS)
    delay(500);
    if (pressure.begin()) {
      if(DEBUG) Serial.println("BMP180 init success");
	} else {
      if(DEBUG) Serial.println("BMP180 init fail");
    }
  #endif

  #ifdef DS18B20
    pinMode(DS18B20_POWER_PIN, OUTPUT);
  #endif

  if(DEBUG) Serial.println("\n");
}

unsigned long t;
void loop(void) {
  if(DEBUG) t = millis();
  measure();
  if(DEBUG) {
    Serial.print("Measuring data took ");
    Serial.print(((millis()-t)));
    Serial.println(" ms");
    Serial.println();
  }
  
  // Every ~5 minutes (37*8s)
  if(DEBUG) {
    delay(3000);
  } else {
    for(int i=0; i<SLEEP_TIME_8S; i++) {
      #ifdef SLEEP_LOWPOWERLIB
        LowPower.powerDown(SLEEP_8S, ADC_OFF, BOD_OFF);
      #endif
      #ifdef SLEEP_NICK
        sleep8s();
      #endif
      #if !defined(SLEEP_LOWPOWERLIB) && !defined(SLEEP_NICK)
        delay(8000);
      #endif
    }
  }
}

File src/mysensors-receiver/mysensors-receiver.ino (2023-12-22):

#include <stdint.h>
#include <VirtualWire.h>

const int rx_pin   = 11;
const int tx_pin   = 5;      // Not connected
const int ptt_pin  = 6;      // Not connected
const int led_pin  = 13;
const int baudrate = 2000;   // Needs to be adjusted on sender side, too

#define INT_MIN    -32768    // Value for "no sensor value available"

// According to mysensors definition
const int V_TEMP     = 0;
const int V_HUM      = 1;
const int V_STATUS   = 2;
const int V_PRESSURE = 4;
const int V_TRIPPED  = 16;
const int V_LEVEL    = 37;

const int S_DOOR     = 0;
const int S_TEMP     = 6;
const int S_HUM      = 7;
const int S_BARO     = 8;
const int S_LIGHT_LEVEL = 16;

const boolean DEBUG = false; // Enable debug mode?

union {
  unsigned char b[2];
  int i = 0;
} b2i;

union {
  unsigned char b[2];
  unsigned int u = 0;
} b2u;

union {
  unsigned char b[4];
  float f = 0;
} b2f;

uint16_t UID = -1;
int sensor_id = 0;
uint8_t MESSAGE_SEQUENCE_NUMBER = 0;

const uint8_t max_known_uids = 32;
uint16_t known_uids[max_known_uids];
bool uid_is_known(uint16_t uid) {
  for(int i=0; i<max_known_uids; i++) {
    if(DEBUG) {
      Serial.print(uid);
      Serial.print(" ");
      Serial.println(known_uids[i]);
    }

    if(known_uids[i] == uid) {
      if(DEBUG) {
        Serial.print("ID KNOWN: ");
        Serial.println(uid);
      }
      return true;
    }
    if(known_uids[i] == 65535) {
      if(DEBUG) {
        Serial.print("ID UNKNOWN: ");
        Serial.println(uid);
      }
      known_uids[i] = uid;
      return false;
    }
  }
  return false;
}

void print_mysensor_presentation() {
  Serial.print(UID/256);
  Serial.println(";255;0;0;0;2.0");

  Serial.print(UID/256);
  Serial.print(";255;3;0;11;");
  Serial.println(UID);

  Serial.print(UID/256);
  Serial.println(";255;3;0;12;1.0");
}

void print_mysensor_string(int is_known, int message_type, int sub_type, float payload) {
  int s_id = sensor_id;
  if(sensor_id == 0) {
    s_id = 255;
  } else {
    s_id = s_id -1;

    if(!is_known) {
      Serial.print(UID/256);
      Serial.print(";");
      Serial.print(s_id);
      Serial.print(";0;0;");
      switch(sub_type) {
        case V_TEMP:
          Serial.print(S_TEMP);
          Serial.print(";Temperature ");
          break;
        case V_HUM:
          Serial.print(S_HUM);
          Serial.print(";Humidity ");
          break;
        case V_PRESSURE:
          Serial.print(S_BARO);
          Serial.print(";Pressure ");
          break;
        case V_TRIPPED:
          Serial.print(S_DOOR);
          Serial.print(";Contact ");
          break;
        case V_LEVEL:
          Serial.print(S_LIGHT_LEVEL);
          Serial.print(";Light ");
          break;
        default:
          Serial.print(";Unknown");
      }
      Serial.println(UID);
    }
  }

  Serial.print(UID/256);
  Serial.print(";");
  Serial.print(s_id);
  Serial.print(";");
  Serial.print(message_type);
  Serial.print(";");
  Serial.print(0);
  Serial.print(";");
  Serial.print(sub_type);
  Serial.print(";");
  if(message_type == 1 && (sub_type == V_TEMP || sub_type == V_HUM)) {
    Serial.println(payload);
  } else {
    Serial.println((int)payload);
  }

  sensor_id+=1;
}

void setup()
{
  Serial.begin(115200);

  for(int i=0; i<max_known_uids; i++) {
    known_uids[i] = 65535;
  }

  vw_set_tx_pin(tx_pin);
  vw_set_rx_pin(rx_pin);
  vw_set_ptt_pin(ptt_pin);
  vw_setup(baudrate);

  vw_rx_start();

  pinMode(led_pin, OUTPUT);
  
  pinMode(9, OUTPUT);
  digitalWrite(9, HIGH);
}

void loop()
{
  uint8_t buf[VW_MAX_MESSAGE_LEN];
  uint8_t buflen = VW_MAX_MESSAGE_LEN;
  sensor_id = 0;

  if (vw_get_message(buf, &buflen)) {
    int i;

    digitalWrite(led_pin, HIGH);

    if(DEBUG) {
      for (i = 0; i < buflen; i++) {
        if((int)buf[i] < 16)
          Serial.print(0);
        Serial.print(buf[i], HEX);
        Serial.print(' ');
      }
      Serial.println();
    }

    if(buf[0] == 0xFF) {
      uint8_t protocol = buf[1];

      uint8_t message_sequence_number = buf[2];

      if(message_sequence_number != MESSAGE_SEQUENCE_NUMBER) {
        MESSAGE_SEQUENCE_NUMBER = message_sequence_number;

        memcpy(b2i.b, buf+3, 2);
        UID = uint16_t(b2i.i);

        bool is_known = uid_is_known(UID);

        memcpy(b2i.b, buf+5, 2);
        float battery_percent = float(b2i.i)/100.0f;

        if(DEBUG) {
          Serial.println("Start found!");
          Serial.print("Protocol Version: ");
          Serial.println(protocol);
          Serial.print("Message Sequence: ");
          Serial.println(message_sequence_number);
          Serial.print("Device UID:       ");
          Serial.println(UID);
          Serial.print("Battery:          ");
          Serial.print(battery_percent, 2);
          Serial.println(" %");
        }

        if(!is_known) {
          print_mysensor_presentation();
        }
        print_mysensor_string(is_known, 3, 0, battery_percent);

        int reader = 7;
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

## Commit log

2015-11-11 added sensor node source code
2015-11-11 added information about the case
2015-11-11 added more sensor images
2015-11-11 added example sensor
2015-11-12 added schematic
2015-11-12 added fritzing schematic file
    [sensor-node.fzz]
2015-11-15 added first version of a window switch
2015-11-15 added schematics
    [window-switch.fzz]
2015-11-15 fixed variable type for time measuring
    [sensor-node.ino]
2015-11-15 wire lib only needed for sensor sketch
2015-11-23 first window switch complete
2015-12-10 Fixed bug in sleep code, readVCC was not working
    [sensor-node.ino, window-switch.ino]
2015-12-29 Changed ports because I short circuit between 3&4 on one board
    [sensor-node.ino]
2015-12-31 Added light sensor
2023-12-22 Implemented presenting the sensors
    To be more compliant with the mysensors standard sensors are now presented
    the first time data is being received. Also the battery value is now sent
    with correct ID.
    [mysensors-receiver.ino]
2024-01-02 Added wall switch with Status LED
